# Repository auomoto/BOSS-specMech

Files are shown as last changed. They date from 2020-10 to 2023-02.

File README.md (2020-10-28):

# BOSS specMech
**_BOSS Spectrograph Mechanicals Controls for the LCO instrument_**

One of the two BOSS spectrographs will be moved to Las Campanas Observatory (LCO). Because existing spare parts inventory is not large enough to support two separate locations, we are replacing the obsolete items on the LCO instrument with currently available parts. One item is the microcontroller board, formerly a Z-World Little Giant, that is no longer manufactured (the original spectrograph was designed in the 1990s).

The new controller is built around a Microchip Curiosity Nano ATMega 4809. The source code and electronics schematics are here.

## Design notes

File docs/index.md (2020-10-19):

## References
1. [specMech Communications Guide](https://docs.google.com/document/d/16dir_fut0HBtZR5ReOcYNGfNxy1jjHzGRPkaTaeYjt8/edit?usp=sharing)
2. [BOSS Spectrograph Technical Manual](https://docs.google.com/document/d/11UHDSXXC8-JnVtt-BcFyOa2BDeodfezanSv0PJa2Pw8/edit?usp=sharing)

## Software Overview
specMech handles the motion controls and sensors on the BOSS spectrographs. The CCD readouts are handled by a different system, the Archon controller.

The specMech target processor is an Atmel ATMega4809 as implemented on a Microchip [dm320115 Curiosity Nano](https://www.microchip.com/DevelopmentTools/ProductDetails/dm320115#additional-summary) board. The programming IDE we use is Atmel Studio 7.0 although one suspects that Microchip's MPLAB X should work with few, if any, code modifications. The Curiosity Nano board was chosen because it does not need an external hardware programming tool to download sofware. Your need only the IDE software and a USB cable.

## Hardware Overview

The original SDSS spectrograph uses a Z-World Little Giant controller board. This board is no longer manufactured so we designed and built a replacment to fit. The design software used is EagleCAD with Fusion360 for layout visualization.

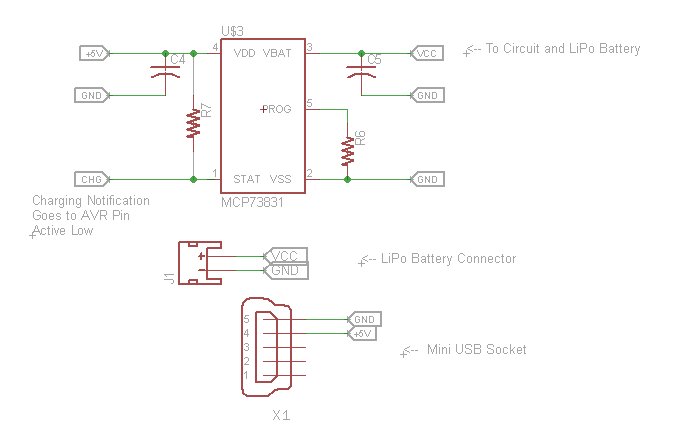
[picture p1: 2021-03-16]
Hardware/Eagle/Project/MCP73831 Circuit.PNG

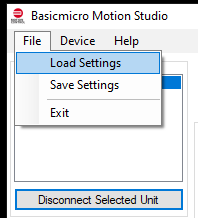
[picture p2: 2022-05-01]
Software/BasicMicro/2022-05-01 Motion Studio Load Settings.PNG

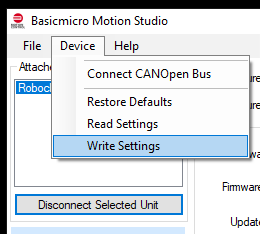
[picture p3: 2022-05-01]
Software/BasicMicro/2022-05-01 Motion Studio Write Settings.PNG

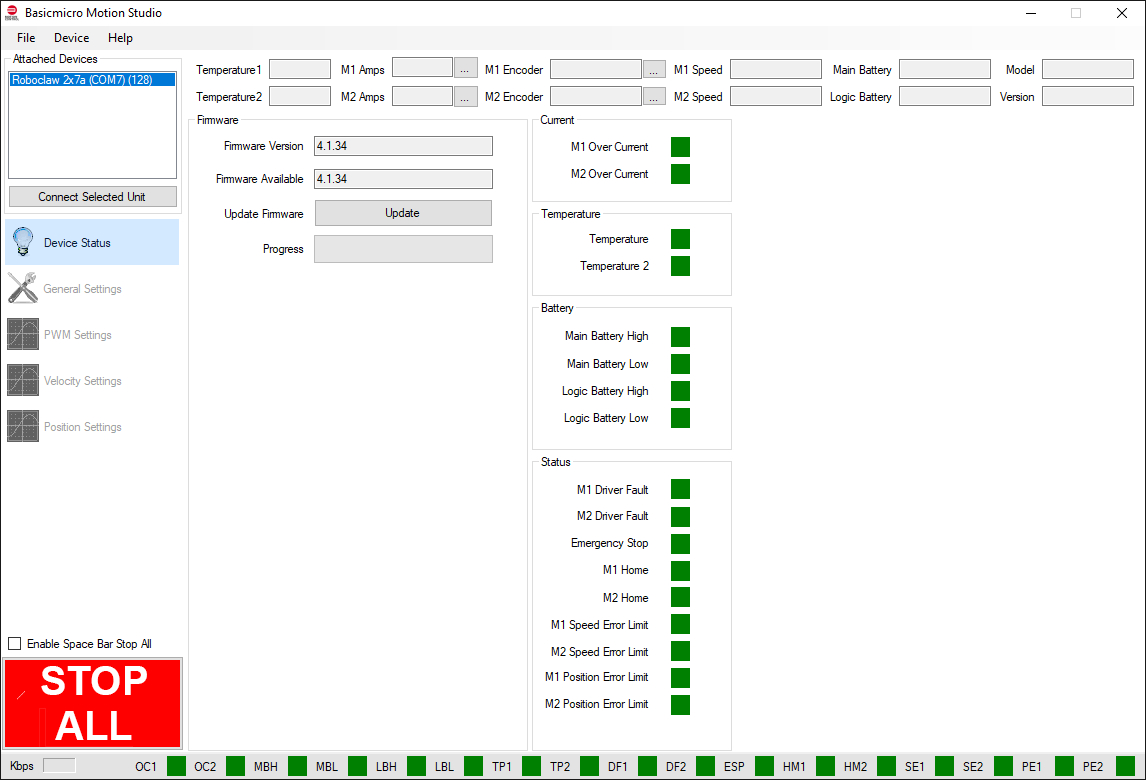
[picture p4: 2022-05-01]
Software/BasicMicro/2022-05-02 Motion Studio Screen Device Status Before.PNG

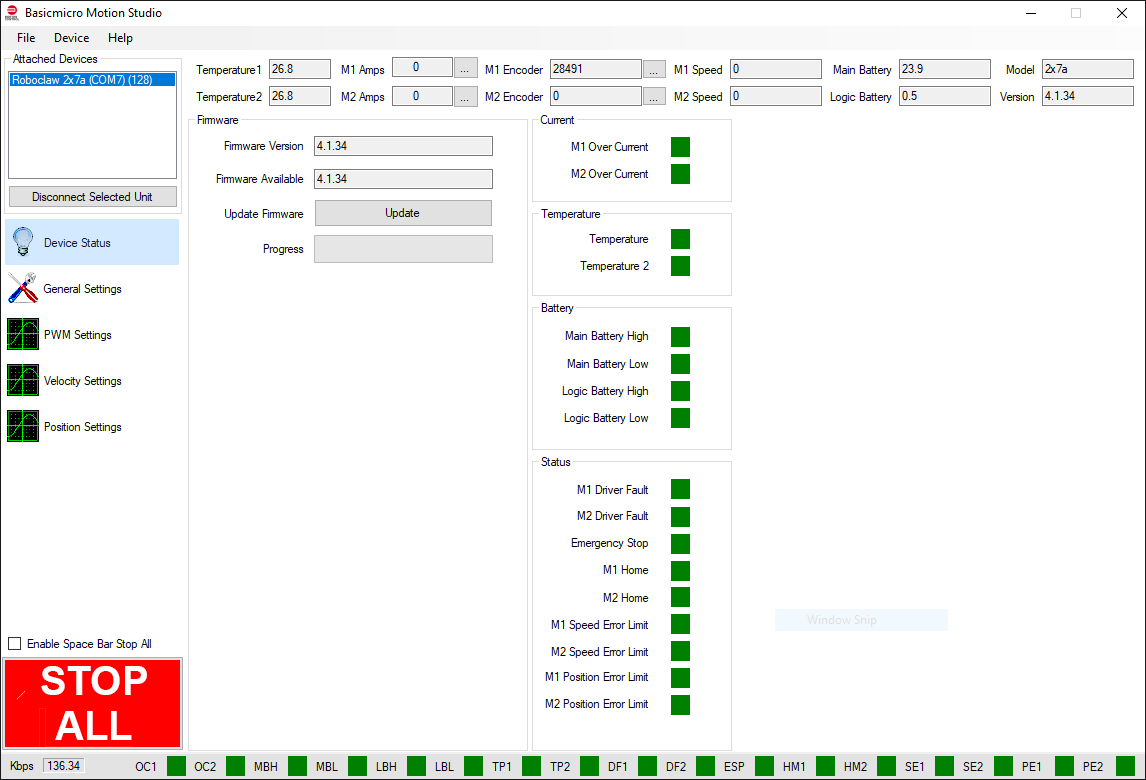
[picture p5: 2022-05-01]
Software/BasicMicro/2022-05-01 Motion Studio Screen Device Status.PNG

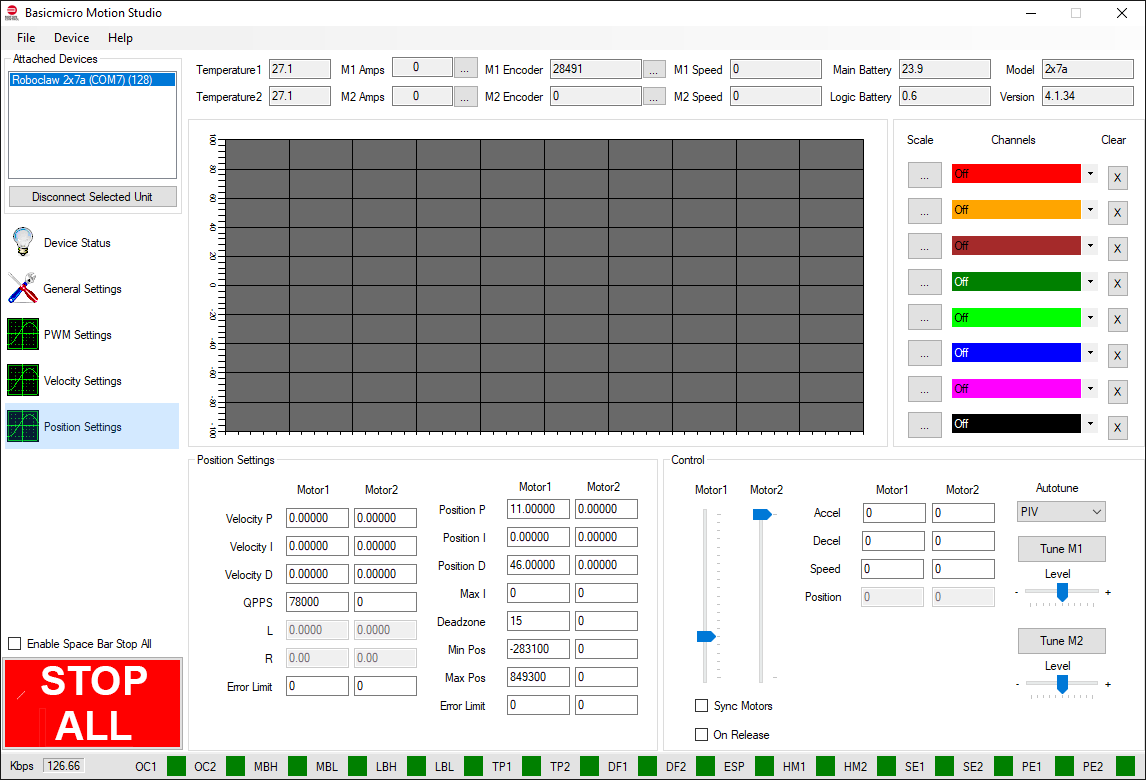
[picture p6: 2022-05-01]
Software/BasicMicro/2022-05-01 Motion Studio Screen Position Settings.PNG

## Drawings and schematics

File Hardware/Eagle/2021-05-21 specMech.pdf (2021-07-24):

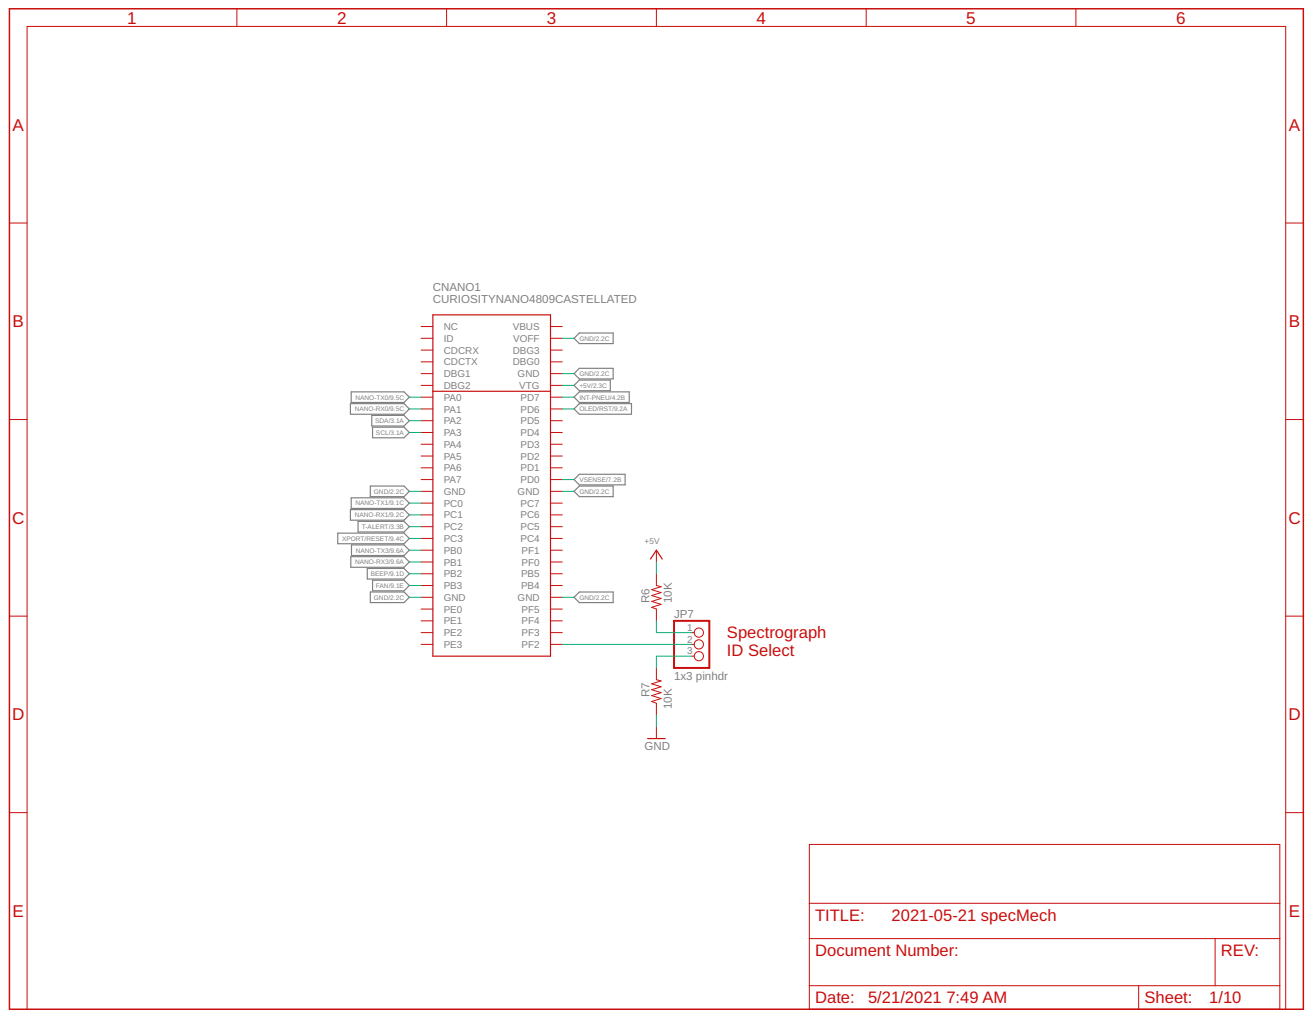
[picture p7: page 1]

Document Number: | REV:

Date: 5/21/2021 7:49 AM | Sheet: 1/10

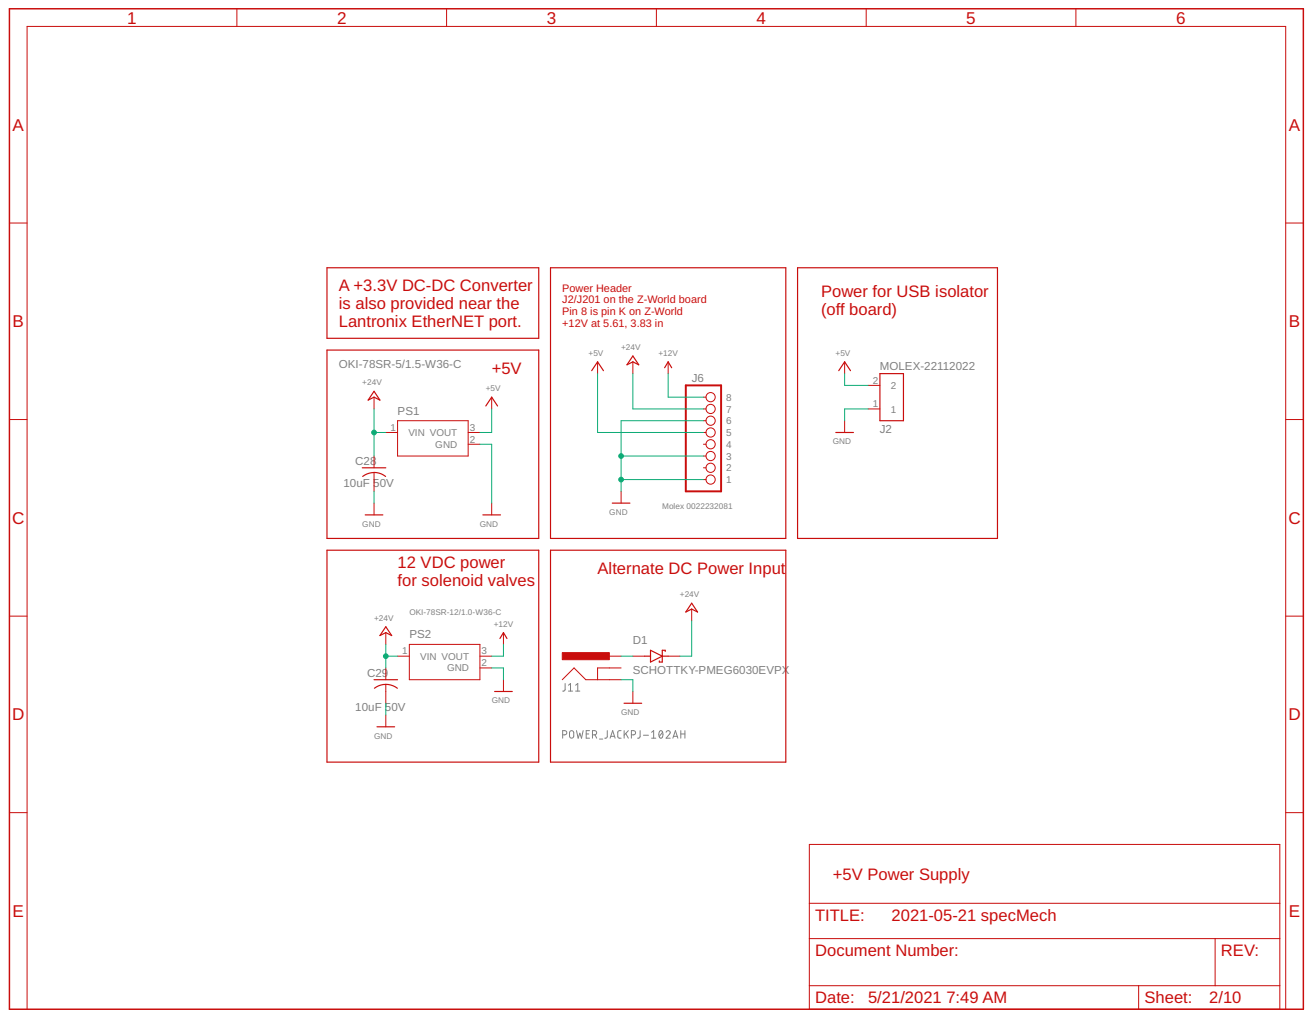
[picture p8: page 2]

Pin 8 is pin K on Z-World +12V at 5.61, 3.83 in A +3.3V DC-DC Converter
is also provided near the
Lantronix EtherNET port.

Power Header J2/J201 on the Z-World board

Power for USB isolator
(off board)

Alternate DC Power Input

Document Number: | REV:

Date: 5/21/2021 7:49 AM | Sheet: 2/10

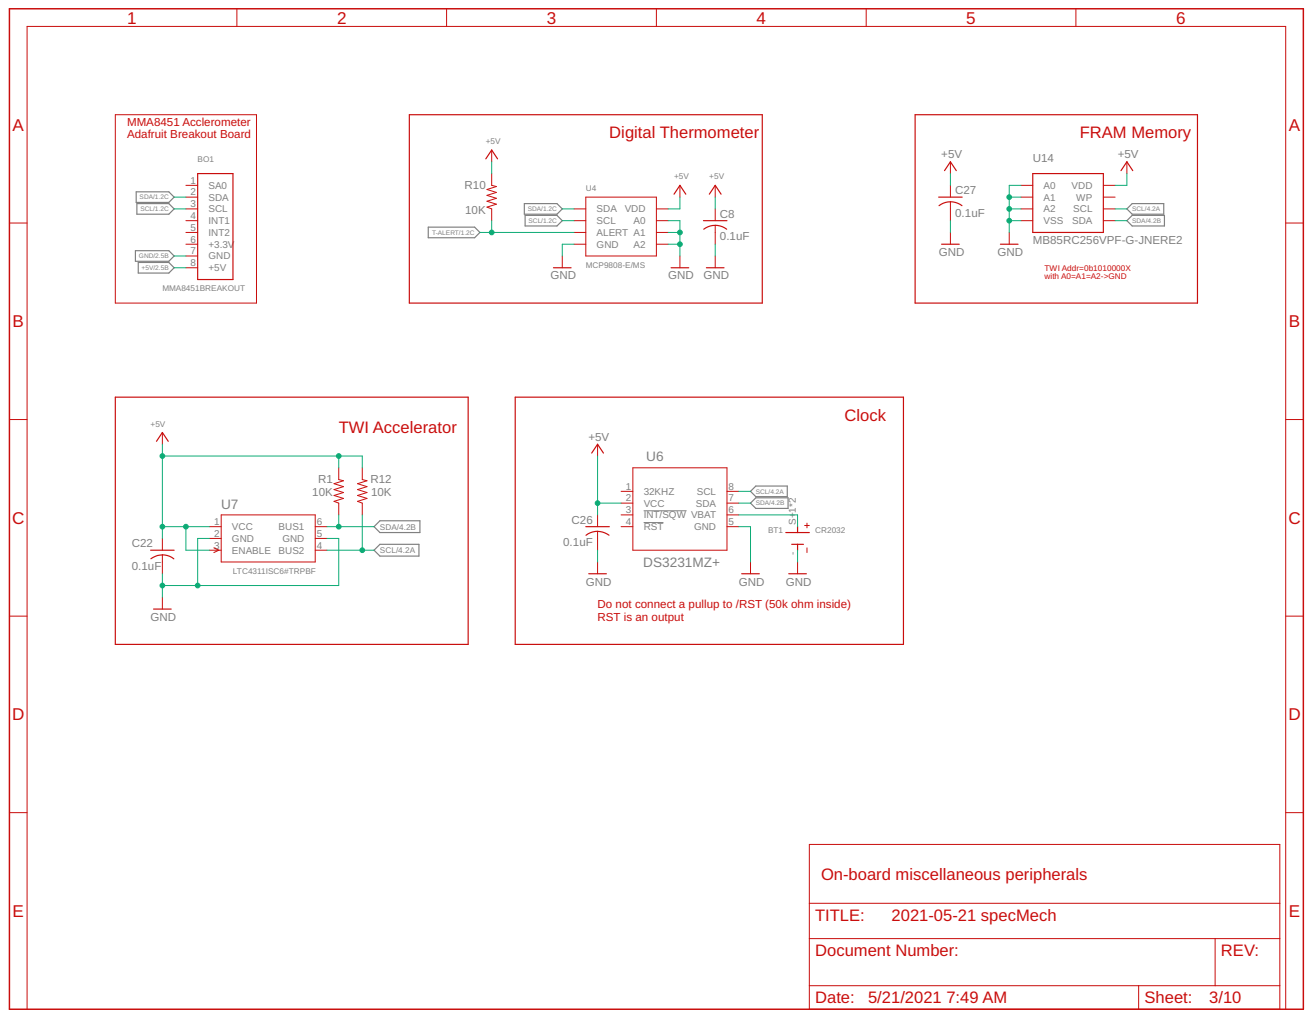
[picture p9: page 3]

MMA8451 Acclerometer Adafruit Breakout Board

TWI Addr=0b1010000X with A0=A1=A2->GND

Do not connect a pullup to /RST (50k ohm inside)
RST is an output

On-board miscellaneous peripherals

Document Number: | REV:

Date: 5/21/2021 7:49 AM | Sheet: 3/10

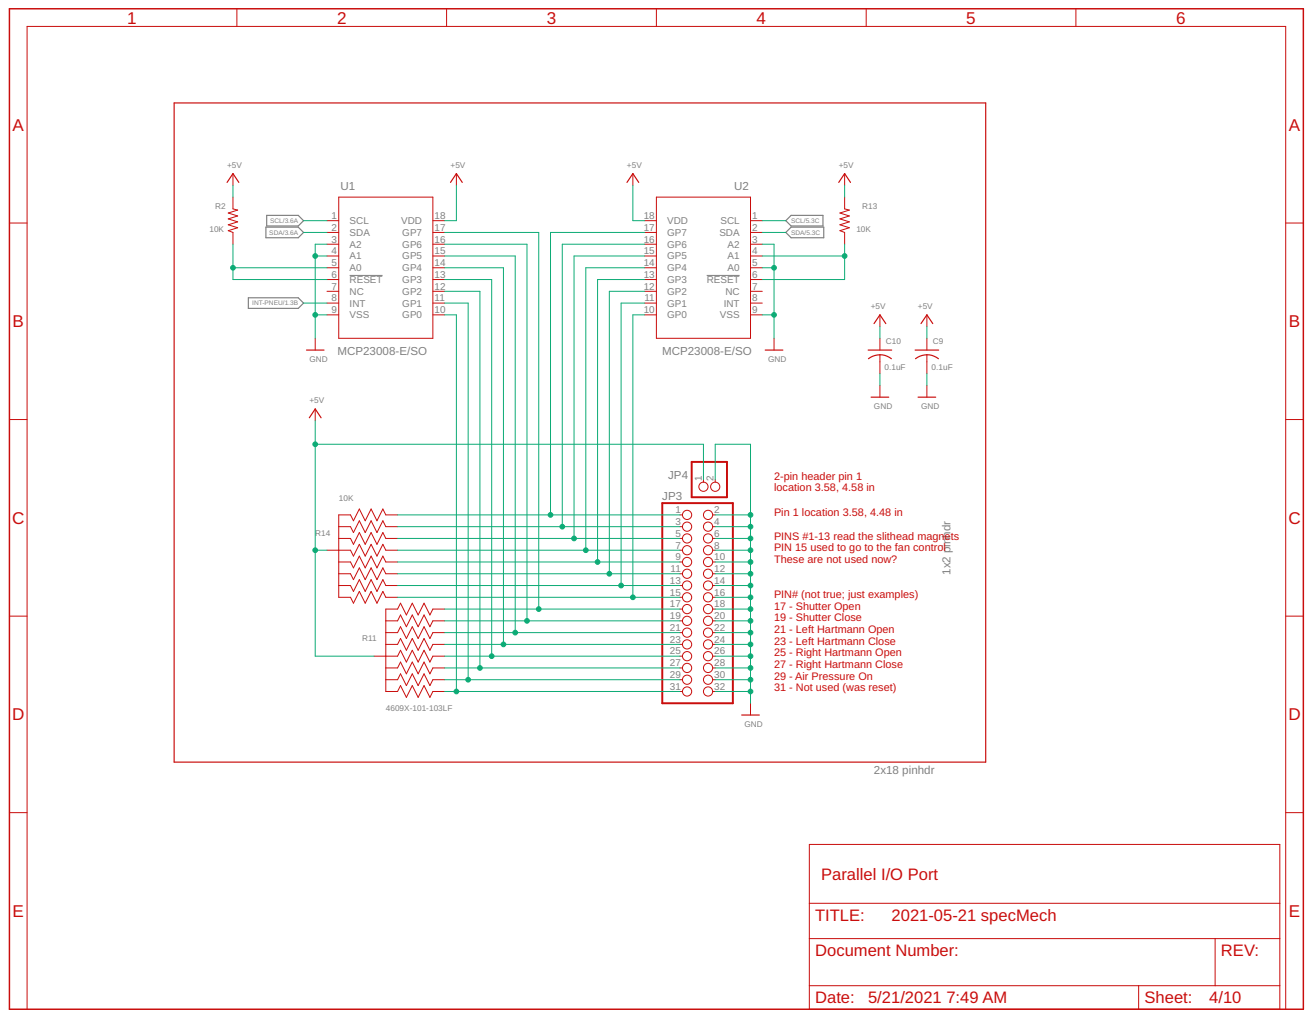
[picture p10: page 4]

Pin 1 location 3.58, 4.48 in PINS #1-13 read the slithead magnets PIN 15 used to go to the fan control

These are not used now?

PIN# (not true; just examples)
17 - Shutter Open
19 - Shutter Close
21 - Left Hartmann Open
23 - Left Hartmann Close
25 - Right Hartmann Open
27 - Right Hartmann Close
29 - Air Pressure On
31 - Not used (was reset)

Document Number: | REV:

Date: 5/21/2021 7:49 AM | Sheet: 4/10

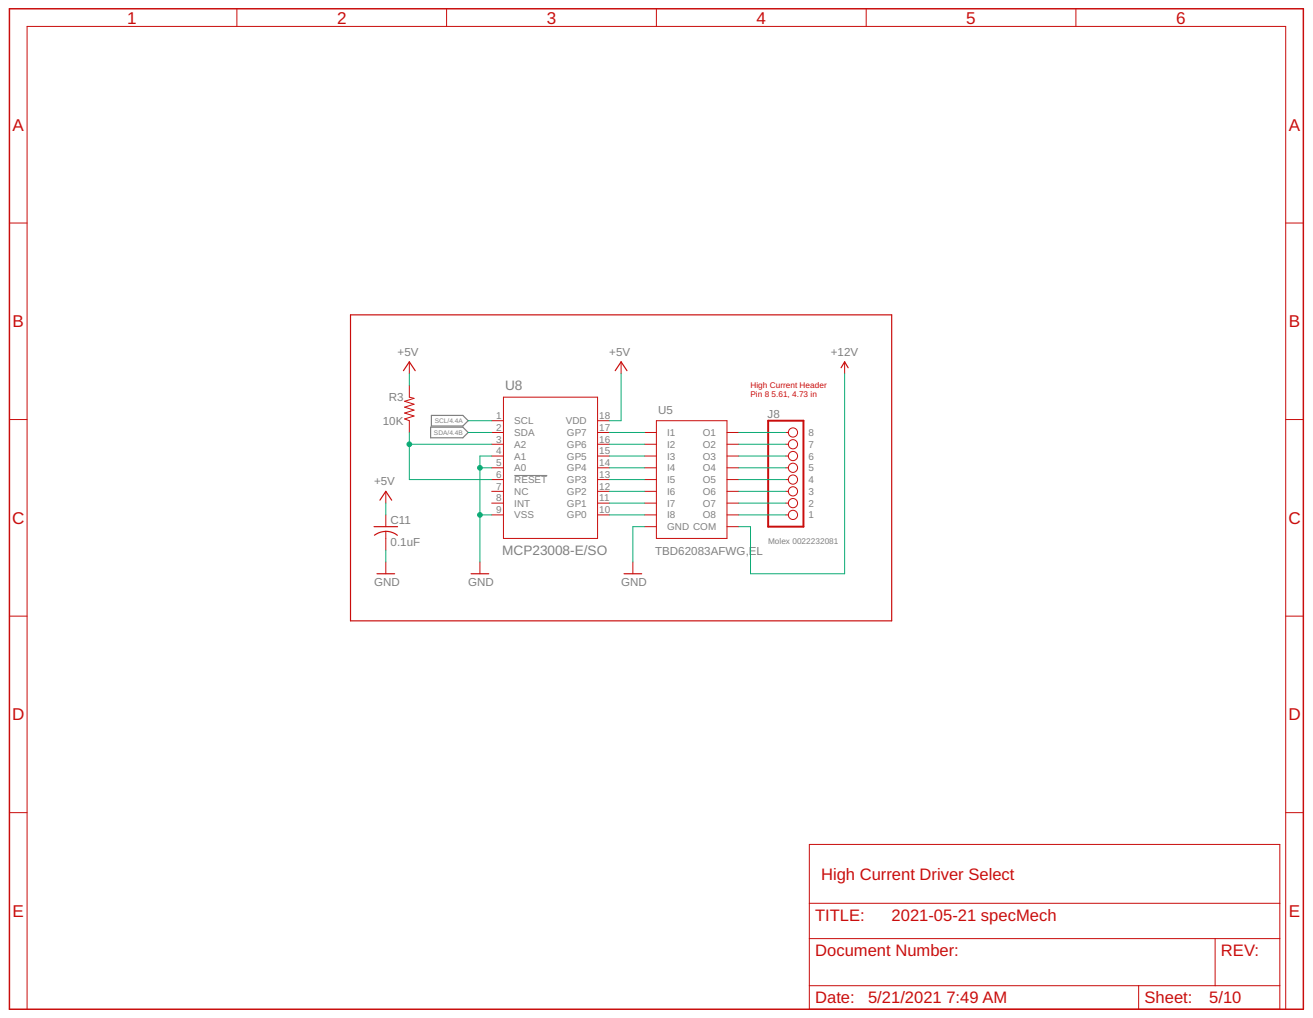
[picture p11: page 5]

High Current Header Pin 8 5.61, 4.73 in

High Current Driver Select

Document Number: | REV:

Date: 5/21/2021 7:49 AM | Sheet: 5/10

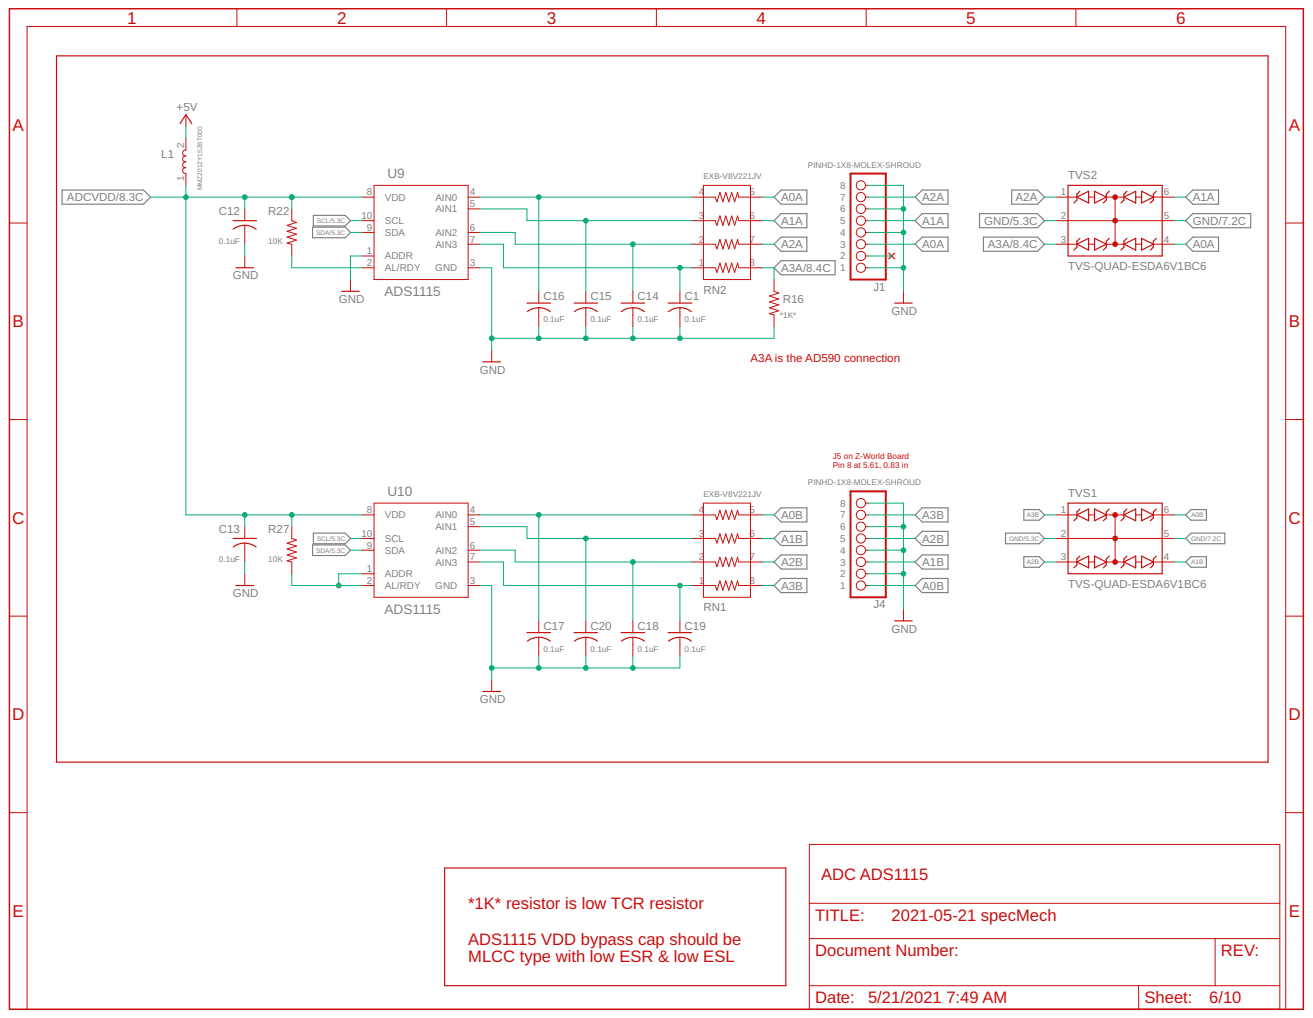
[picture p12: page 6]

J5 on Z-World Board Pin 8 at 5.61, 0.83 in

*1K* resistor is low TCR resistor

ADS1115 VDD bypass cap should be
MLCC type with low ESR & low ESL

Document Number: | REV:

Date: 5/21/2021 7:49 AM | Sheet: 6/10

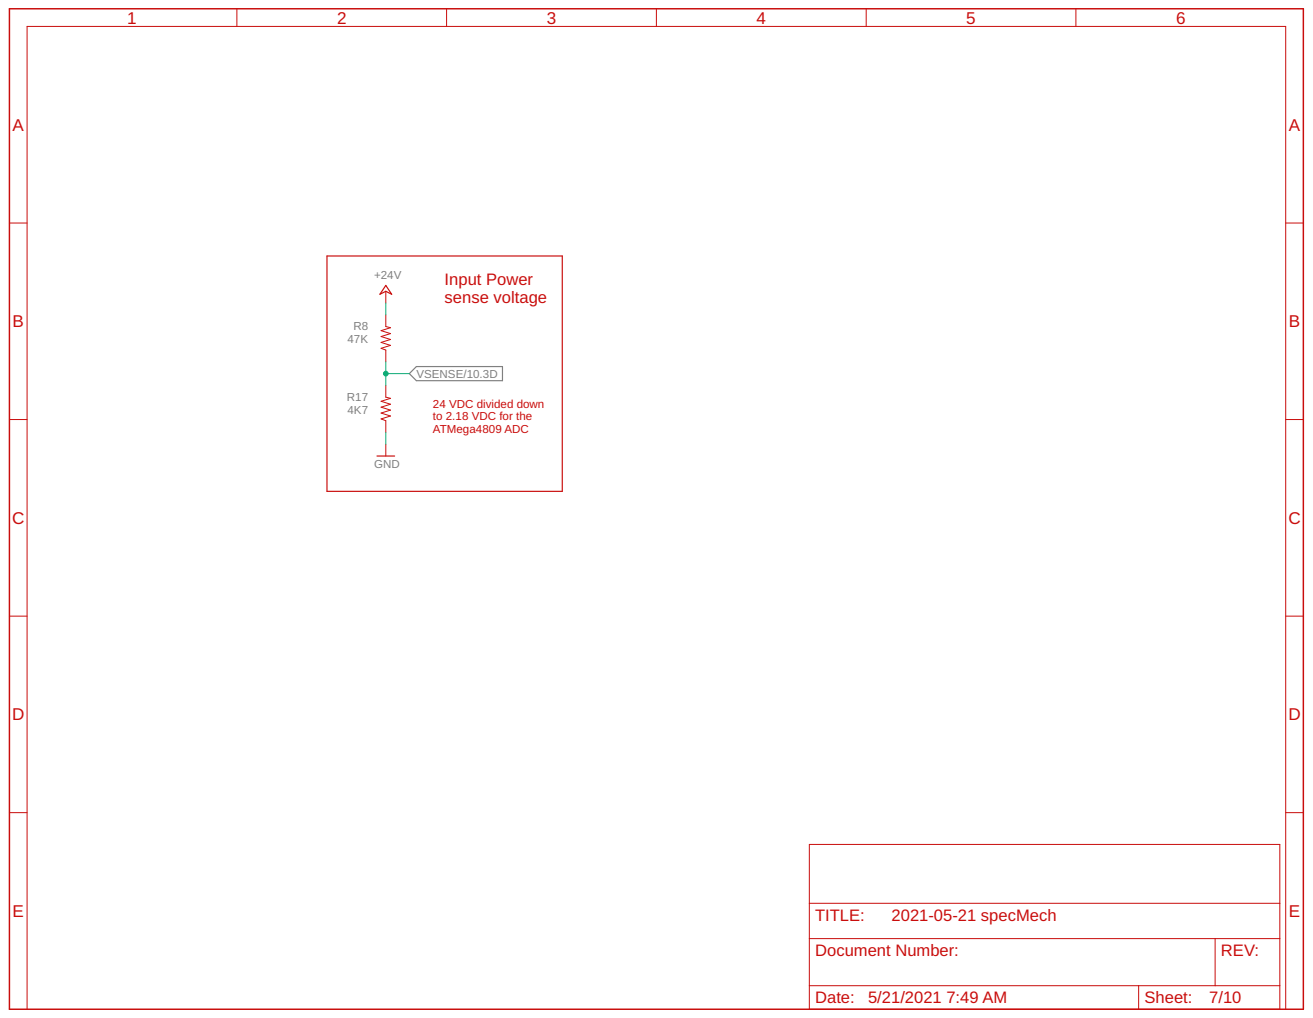
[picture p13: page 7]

24 VDC divided down
to 2.18 VDC for the ATMega4809 ADC

Document Number: | REV:

Date: 5/21/2021 7:49 AM | Sheet: 7/10

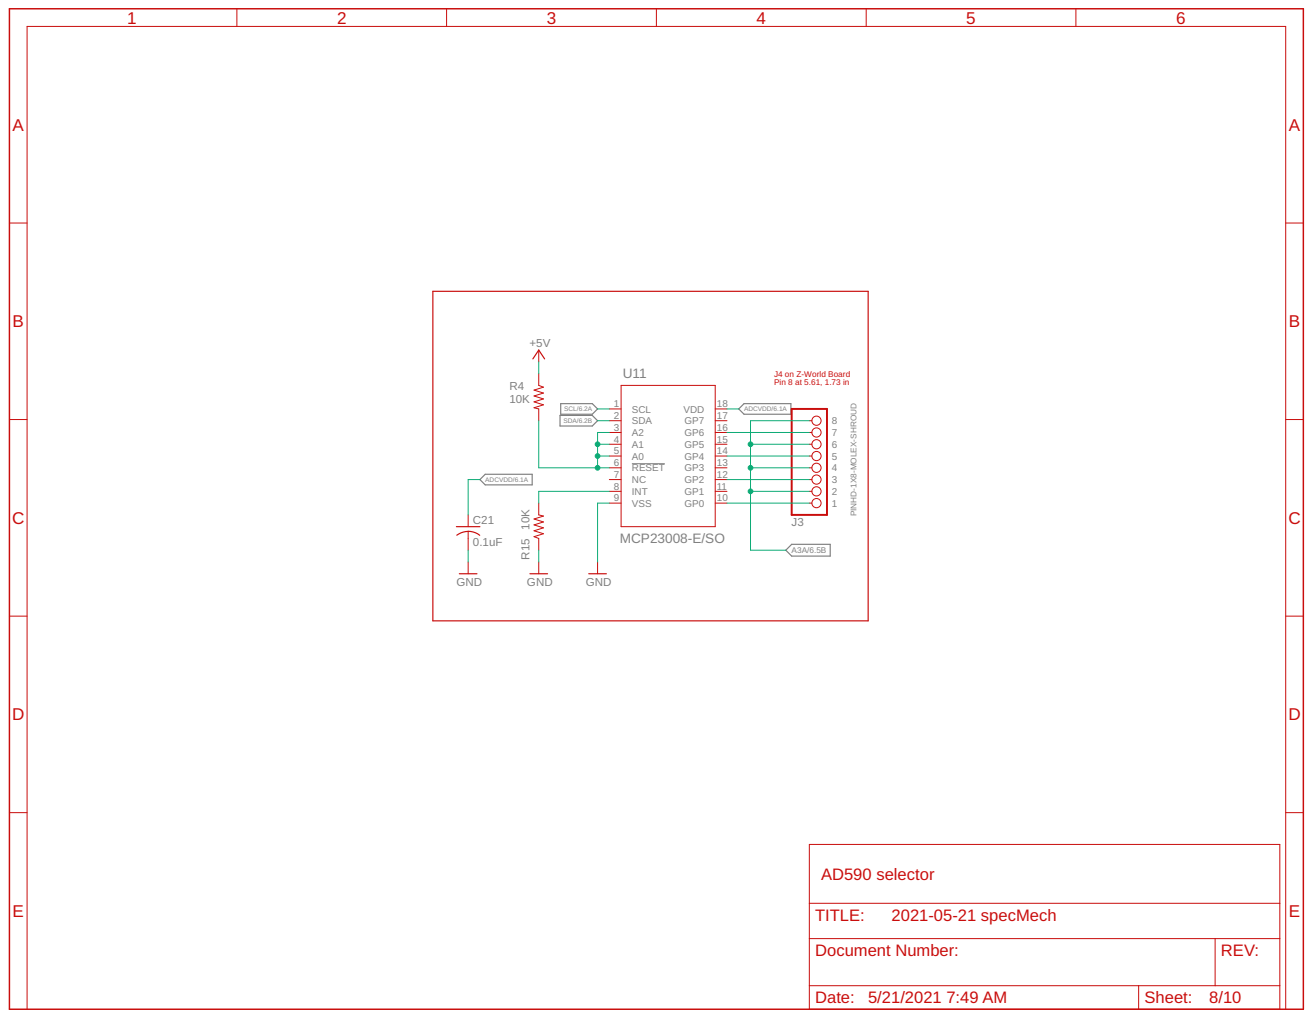
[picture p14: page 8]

J4 on Z-World Board Pin 8 at 5.61, 1.73 in

Document Number: | REV:

Date: 5/21/2021 7:49 AM | Sheet: 8/10

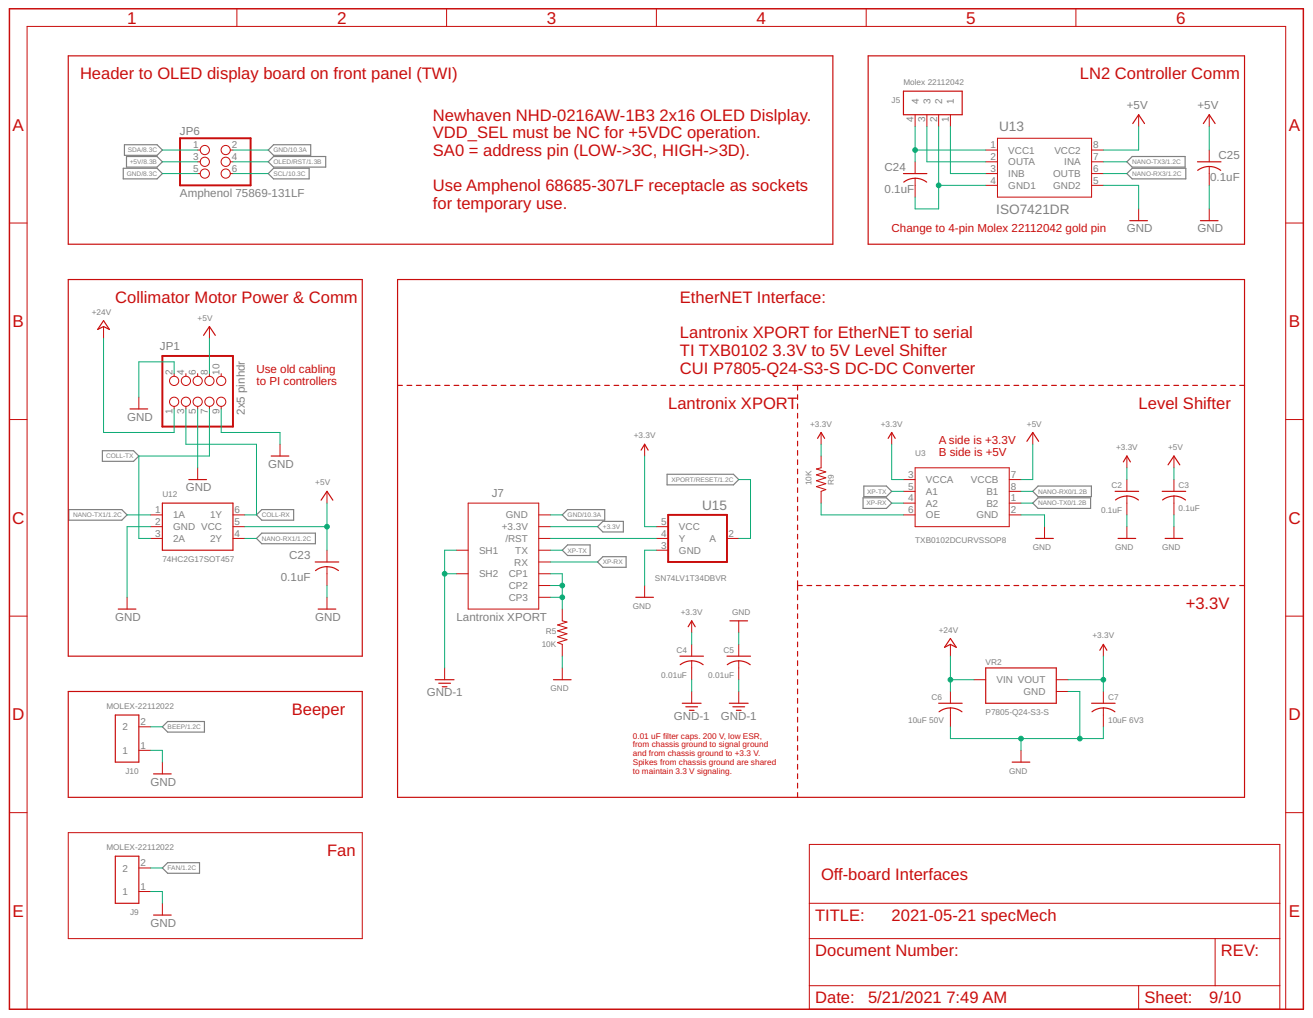
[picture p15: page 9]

Header to OLED display board on front panel (TWI)

Newhaven NHD-0216AW-1B3 2x16 OLED Dislplay. VDD_SEL must be NC for +5VDC operation. SA0 = address pin (LOW->3C, HIGH->3D). Use Amphenol 68685-307LF receptacle as sockets

Change to 4-pin Molex 22112042 gold pin

Collimator Motor Power & Comm

Lantronix XPORT for EtherNET to serial
TI TXB0102 3.3V to 5V Level Shifter
CUI P7805-Q24-S3-S DC-DC Converter

0.01 uF filter caps. 200 V, low ESR,
from chassis ground to signal ground
and from chassis ground to +3.3 V. Spikes from chassis ground are shared

Document Number: | REV:

Date: 5/21/2021 7:49 AM | Sheet: 9/10

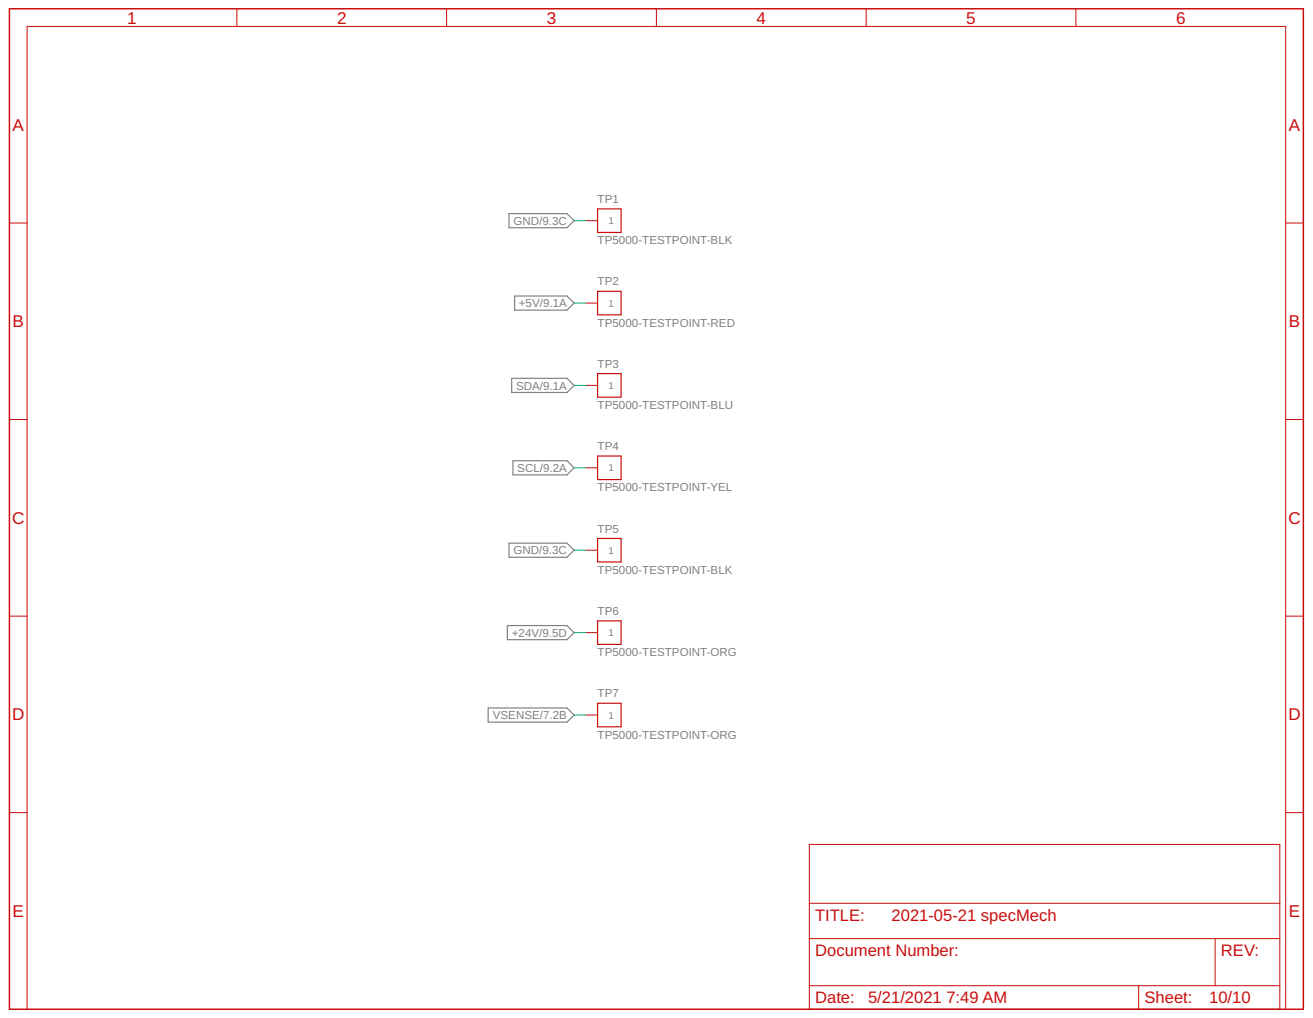
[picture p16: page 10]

Document Number: | REV:

Date: 5/21/2021 7:49 AM | Sheet: 10/10

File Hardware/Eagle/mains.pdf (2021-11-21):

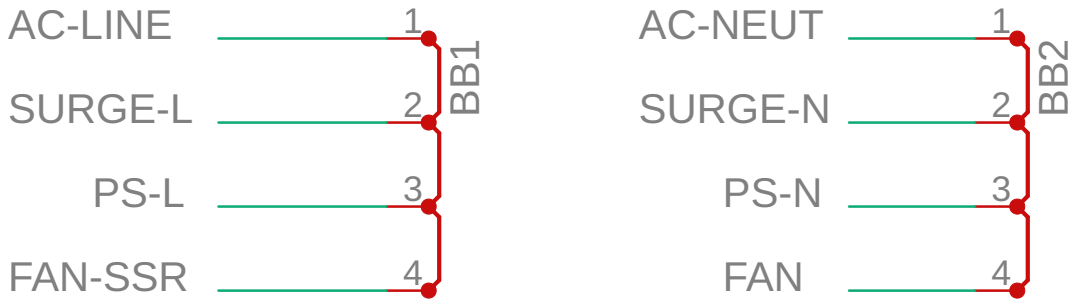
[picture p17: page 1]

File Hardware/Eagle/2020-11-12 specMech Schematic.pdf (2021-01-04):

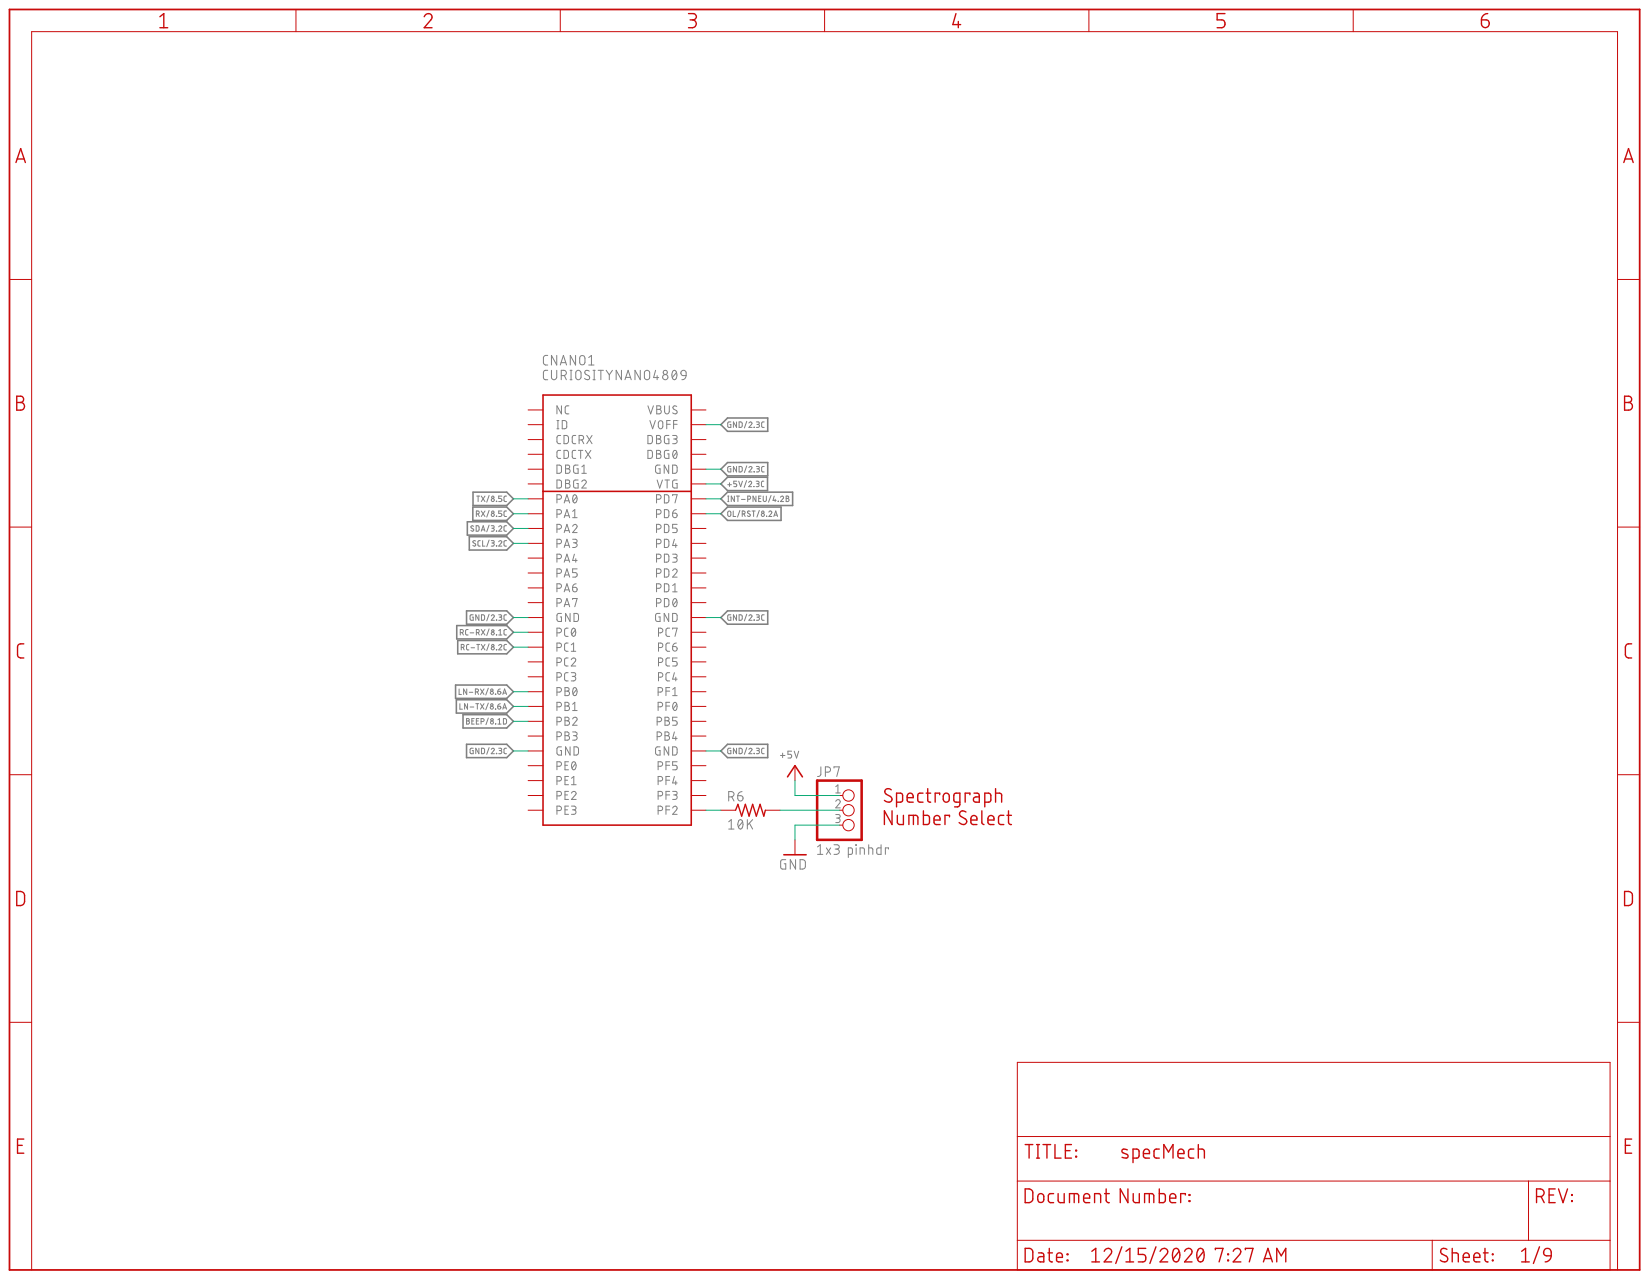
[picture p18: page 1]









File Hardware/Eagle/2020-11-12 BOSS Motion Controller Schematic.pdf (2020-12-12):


12/11/2020 4:51 PM f=1.26 G:\My Drive\Github\BOSS-specMech\Hardware\Eagle\specMech.sch (Sheet: 1/9)


12/11/2020 4:51 PM f=1.26 G:\My Drive\Github\BOSS-specMech\Hardware\Eagle\specMech.sch (Sheet: 2/9)


12/11/2020 4:51 PM f=1.26 G:\My Drive\Github\BOSS-specMech\Hardware\Eagle\specMech.sch (Sheet: 3/9)


12/11/2020 4:51 PM f=1.26 G:\My Drive\Github\BOSS-specMech\Hardware\Eagle\specMech.sch (Sheet: 4/9)


12/11/2020 4:51 PM f=1.26 G:\My Drive\Github\BOSS-specMech\Hardware\Eagle\specMech.sch (Sheet: 5/9)


12/11/2020 4:51 PM f=1.26 G:\My Drive\Github\BOSS-specMech\Hardware\Eagle\specMech.sch (Sheet: 6/9)


12/11/2020 4:51 PM f=1.26 G:\My Drive\Github\BOSS-specMech\Hardware\Eagle\specMech.sch (Sheet: 7/9)


12/11/2020 4:51 PM f=1.26 G:\My Drive\Github\BOSS-specMech\Hardware\Eagle\specMech.sch (Sheet: 8/9)


12/11/2020 4:51 PM f=1.26 G:\My Drive\Github\BOSS-specMech\Hardware\Eagle\specMech.sch (Sheet: 9/9)

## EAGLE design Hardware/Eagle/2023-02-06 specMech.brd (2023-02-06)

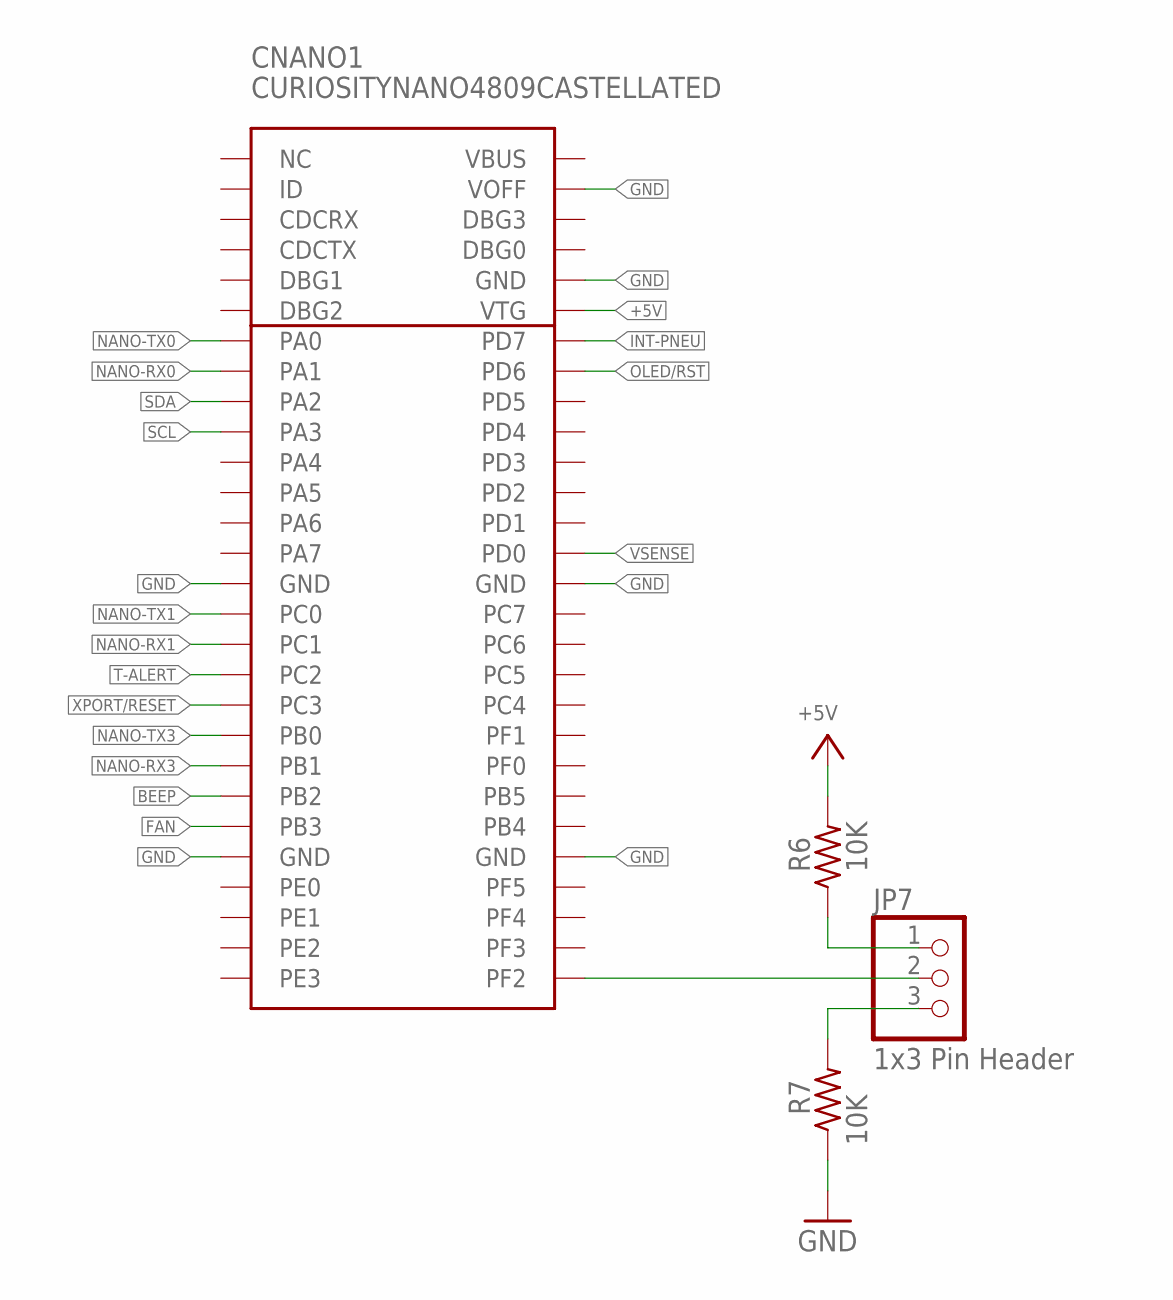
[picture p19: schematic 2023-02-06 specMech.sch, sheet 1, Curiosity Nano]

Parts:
CNANO1: CURIOSITYNANO4809CASTELLATED
JP7: 1x3 Pin Header; 1X03
R6, R7: 10K; R0805

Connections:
+5V: CNANO1.VTG, R6.2; also elsewhere on the board
BEEP: CNANO1.PB2; also elsewhere on the board
FAN: CNANO1.PB3; also elsewhere on the board
GND: CNANO1.GND15 (GND), CNANO1.GND24 (GND), CNANO1.GND33 (GND), CNANO1.GND42 (GND), CNANO1.GND52 (GND), CNANO1.VOFF, R7.1; also elsewhere on the board
INT-PNEU: CNANO1.PD7-AIN7 (PD7); also elsewhere on the board
unnamed: CNANO1.PF2, JP7.2
unnamed: JP7.3, R7.2
unnamed: JP7.1, R6.1
NANO-RX0: CNANO1.PA1-RX (PA1); also elsewhere on the board
NANO-RX1: CNANO1.PC1-RX (PC1); also elsewhere on the board
NANO-RX3: CNANO1.PB1-RX (PB1); also elsewhere on the board
NANO-TX0: CNANO1.PA0-TX (PA0); also elsewhere on the board
NANO-TX1: CNANO1.PC0-TX (PC0); also elsewhere on the board
NANO-TX3: CNANO1.PB0-TX (PB0); also elsewhere on the board
OLED/RST: CNANO1.PD6-AIN6 (PD6); also elsewhere on the board
SCL: CNANO1.PA3-SCL (PA3); also elsewhere on the board
SDA: CNANO1.PA2-SDA (PA2); also elsewhere on the board
T-ALERT: CNANO1.PC2; also elsewhere on the board
VSENSE: CNANO1.PD0-AIN0 (PD0); also elsewhere on the board
XPORT/RESET: CNANO1.PC3; also elsewhere on the board

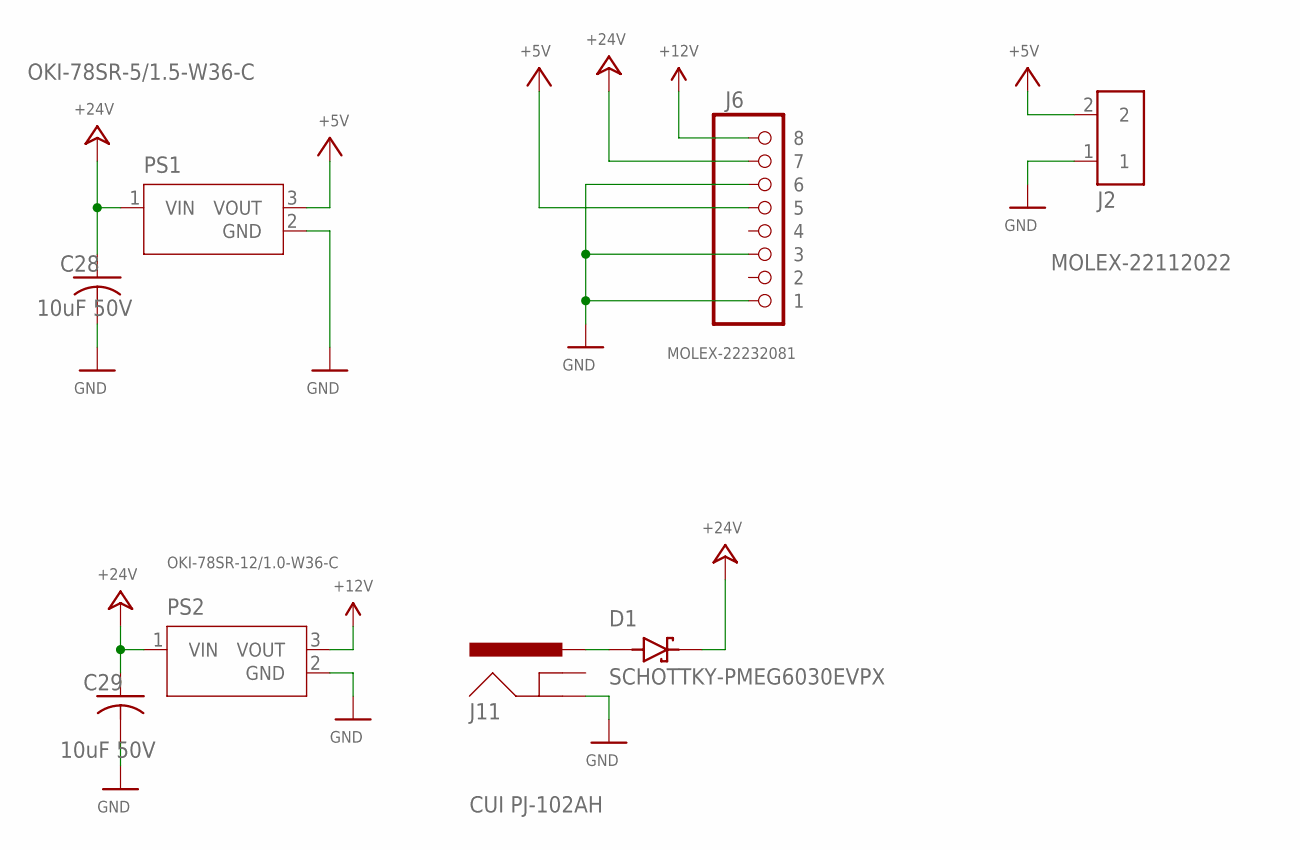
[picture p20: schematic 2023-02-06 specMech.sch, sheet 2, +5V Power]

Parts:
C28, C29: 10uF 50V; C1210
D1: SCHOTTKY-PMEG6030EVPX; DIO_PMEG6030EVPX
J2: MOLEX-22112022; 1X02-MOLEX-22112022
J6: MOLEX-22232081; 1X08-MOLEX-SHROUD
J11: CUI PJ-102AH; PJ-102AH
PS1: OKI-78SR-5/1.5-W36-C; CONV_OKI-78SR-5/1.5-W36-C
PS2: OKI-78SR-12/1.0-W36-C; CONV_OKI-78SR-5/1.5-W36-C

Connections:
+5V: J2.2, J6.P$5 (5), PS1.3 (VOUT); also elsewhere on the board
+12V: J6.P$8 (8), PS2.3 (VOUT); also elsewhere on the board
+24V: C28.1, C29.1, D1.1 (K), J6.P$7 (7), PS1.1 (VIN), PS2.1 (VIN); also elsewhere on the board
GND: C28.2, C29.2, J2.1, J6.P$1 (1), J6.P$3 (3), J6.P$6 (6), J11.GND, PS1.2 (GND), PS2.2 (GND); also elsewhere on the board
unnamed: D1.2 (A), J11.PWR

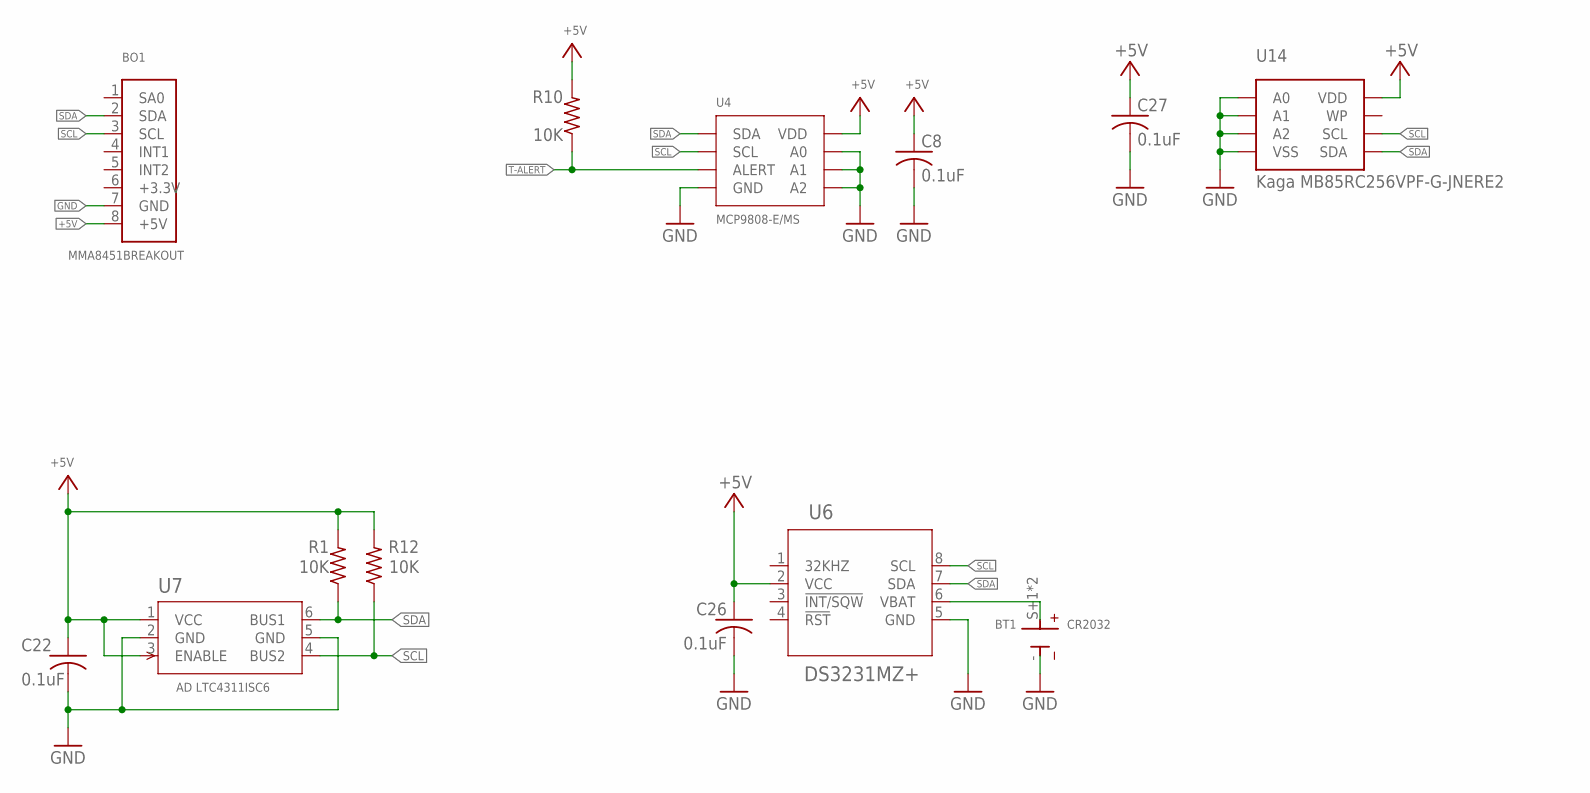
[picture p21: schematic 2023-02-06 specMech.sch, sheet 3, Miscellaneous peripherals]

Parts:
BO1: MMA8451BREAKOUT; 1X08
BT1: CR2032; BAT_BK-5058
C8, C22, C26, C27: 0.1uF; C0805
R1, R10, R12: 10K; R0805
U4: MCP9808-E/MS; MSOP8_MC_MCH
U6: DS3231MZ+; 21-0041B_8
U7: AD LTC4311ISC6; SOT-6_SC_LIT
U14: Kaga MB85RC256VPF-G-JNERE2; SOIC127P797X210-8N

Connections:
+5V: BO1.8 (+5V), C8.1, C22.1, C26.1, C27.1, R1.2, R10.2, R12.2, U4.8 (VDD), U6.2 (VCC), U7.1 (VCC), U7.3 (ENABLE), U14.8 (VDD); also elsewhere on the board
GND: BO1.7 (GND), BT1.-, C8.2, C22.2, C26.2, C27.2, U4.4 (GND), U4.5 (A2), U4.6 (A1), U4.7 (A0), U6.5 (GND), U7.2 (GND), U7.5 (GND), U14.1 (A0), U14.2 (A1), U14.3 (A2), U14.4 (VSS); also elsewhere on the board
SCL: BO1.3 (SCL), R12.1, U4.2 (SCL), U6.8 (SCL), U7.4 (BUS2), U14.6 (SCL); also elsewhere on the board
SDA: BO1.2 (SDA), R1.1, U4.1 (SDA), U6.7 (SDA), U7.6 (BUS1), U14.5 (SDA); also elsewhere on the board
T-ALERT: R10.1, U4.3 (ALERT); also elsewhere on the board
VBAT: BT1.S+1 (+), BT1.S+2 (+), U6.6 (VBAT)

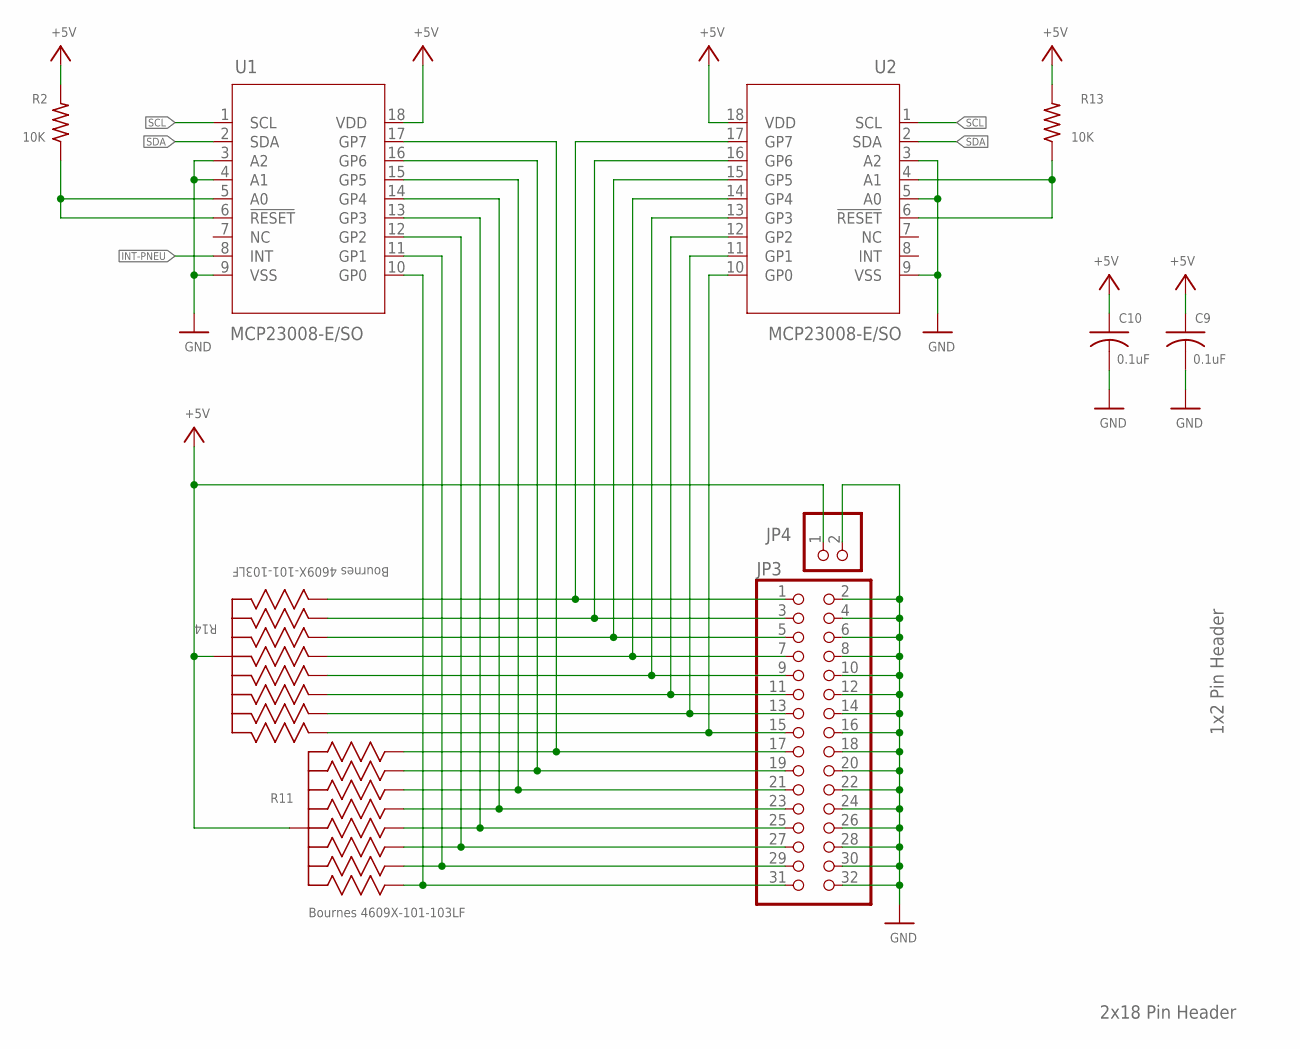
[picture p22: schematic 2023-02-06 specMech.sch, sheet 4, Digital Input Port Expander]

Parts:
C9, C10: 0.1uF; C0805
JP3: 2x18 Pin Header; 2X16
JP4: 1x2 Pin Header; 1X02
R2, R13: 10K; R0805
R11, R14: Bournes 4609X-101-103LF; BO_4609X
U1, U2: MCP23008-E/SO; SOIC18-W_MC

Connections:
+5V: C9.1, C10.1, JP4.1, R2.2, R11.1, R13.2, R14.1, U1.18 (VDD), U2.18 (VDD); also elsewhere on the board
GND: C9.2, C10.2, JP3.2, JP3.4, JP3.6, JP3.8, JP3.10, JP3.12, JP3.14, JP3.16, JP3.18, JP3.20, JP3.22, JP3.24, JP3.26, JP3.28, JP3.30, JP3.32, JP4.2, U1.3 (A2), U1.4 (A1), U1.9 (VSS), U2.3 (A2), U2.5 (A0), U2.9 (VSS); also elsewhere on the board
INT-PNEU: U1.8 (INT); also elsewhere on the board
unnamed: JP3.1, R14.2, U2.17 (GP7)
unnamed: JP3.3, R14.3, U2.16 (GP6)
unnamed: JP3.5, R14.4, U2.15 (GP5)
unnamed: JP3.7, R14.5, U2.14 (GP4)
unnamed: JP3.17, R11.9, U1.17 (GP7)
unnamed: JP3.19, R11.8, U1.16 (GP6)
unnamed: JP3.21, R11.7, U1.15 (GP5)
unnamed: JP3.23, R11.6, U1.14 (GP4)
unnamed: JP3.25, R11.5, U1.13 (GP3)
unnamed: R2.1, U1.5 (A0), U1.6 (!RESET)
unnamed: JP3.29, R11.3, U1.11 (GP1)
unnamed: JP3.31, R11.2, U1.10 (GP0)
unnamed: JP3.11, R14.7, U2.12 (GP2)
unnamed: JP3.27, R11.4, U1.12 (GP2)
unnamed: JP3.13, R14.8, U2.11 (GP1)
unnamed: JP3.15, R14.9, U2.10 (GP0)
unnamed: R13.1, U2.4 (A1), U2.6 (!RESET)
unnamed: JP3.9, R14.6, U2.13 (GP3)
SCL: U1.1 (SCL), U2.1 (SCL); also elsewhere on the board
SDA: U1.2 (SDA), U2.2 (SDA); also elsewhere on the board

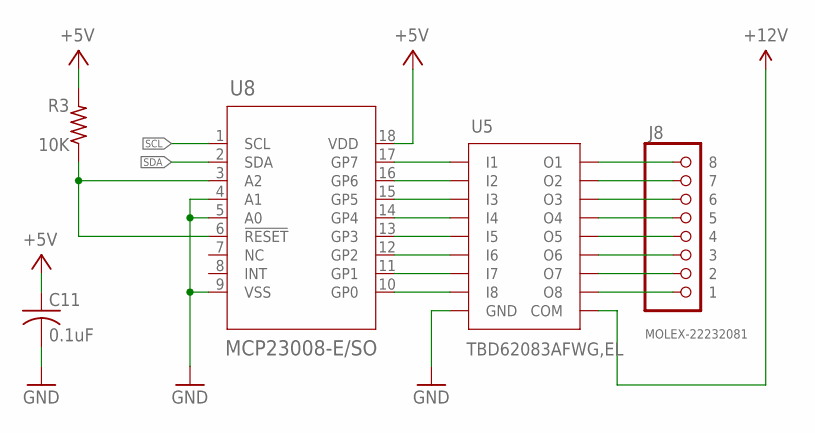
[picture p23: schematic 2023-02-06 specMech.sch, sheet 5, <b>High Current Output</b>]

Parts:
C11: 0.1uF; C0805
J8: MOLEX-22232081; 1X08-MOLEX-SHROUD
R3: 10K; R0805
U5: TBD62083AFWG,EL; SOIC127P1030X245-18
U8: MCP23008-E/SO; SOIC18-W_MC

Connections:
+5V: C11.1, R3.2, U8.18 (VDD); also elsewhere on the board
+12V: U5.10 (COM); also elsewhere on the board
GND: C11.2, U5.9 (GND), U8.4 (A1), U8.5 (A0), U8.9 (VSS); also elsewhere on the board
unnamed: U5.1 (I1), U8.17 (GP7)
unnamed: U5.2 (I2), U8.16 (GP6)
unnamed: U5.3 (I3), U8.15 (GP5)
unnamed: U5.4 (I4), U8.14 (GP4)
unnamed: U5.5 (I5), U8.13 (GP3)
unnamed: U5.6 (I6), U8.12 (GP2)
unnamed: U5.7 (I7), U8.11 (GP1)
unnamed: U5.8 (I8), U8.10 (GP0)
unnamed: R3.1, U8.3 (A2), U8.6 (!RESET)
unnamed: J8.P$8 (8), U5.18 (O1)
unnamed: J8.P$1 (1), U5.11 (O8)
unnamed: J8.P$2 (2), U5.12 (O7)
unnamed: J8.P$3 (3), U5.13 (O6)
unnamed: J8.P$4 (4), U5.14 (O5)
unnamed: J8.P$5 (5), U5.15 (O4)
unnamed: J8.P$6 (6), U5.16 (O3)
unnamed: J8.P$7 (7), U5.17 (O2)
SCL: U8.1 (SCL); also elsewhere on the board
SDA: U8.2 (SDA); also elsewhere on the board

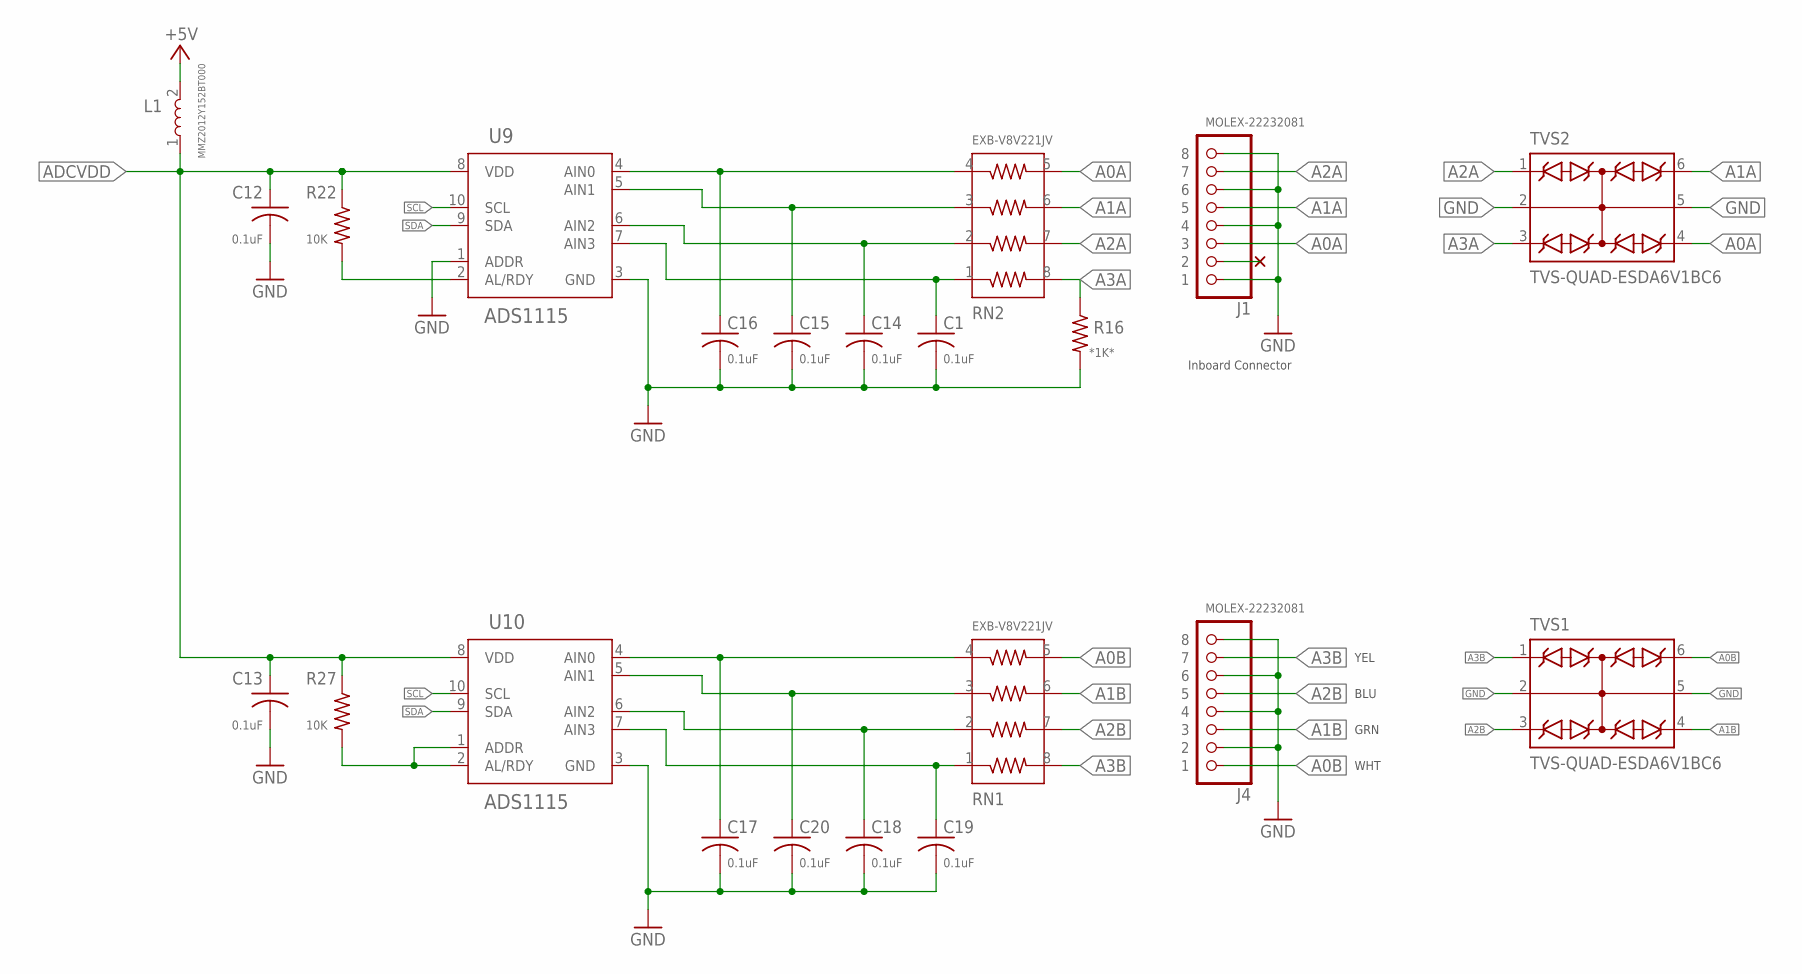
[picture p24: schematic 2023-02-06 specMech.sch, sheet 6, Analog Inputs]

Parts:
C1, C12, C13, C14, C15, C16, C17, C18, C19, C20: 0.1uF; C0805
J1, J4: MOLEX-22232081; 1X08-MOLEX-SHROUD
L1: MMZ2012Y152BT000; INDC2012X87N
R16: *1K*; R0805
R22, R27: 10K; R0805
RN1, RN2: EXB-V8V221JV; EXB38V_PAN
TVS1, TVS2: TVS-QUAD-ESDA6V1BC6; SOT95P280X145-6N
U9, U10: ADS1115; SOP50P490X110-10N

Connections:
+5V: L1.2; also elsewhere on the board
A0A: J1.P$3 (3), RN2.5, TVS2.4 (C3)
A0B: J4.P$1 (1), RN1.5, TVS1.6 (C4)
A1A: J1.P$5 (5), RN2.6, TVS2.6 (C4)
A1B: J4.P$3 (3), RN1.6, TVS1.4 (C3)
A2A: J1.P$7 (7), RN2.7, TVS2.1 (C1)
A2B: J4.P$5 (5), RN1.7, TVS1.3 (C2)
A3A: R16.1, RN2.8, TVS2.3 (C2); also elsewhere on the board
A3B: J4.P$7 (7), RN1.8, TVS1.1 (C1)
ADCVDD: C12.1, C13.1, L1.1, R22.1, R27.1, U9.8 (VDD), U10.8 (VDD); also elsewhere on the board
GND: C1.2, C12.2, C13.2, C14.2, C15.2, C16.2, C17.2, C18.2, C19.2, C20.2, J1.P$1 (1), J1.P$4 (4), J1.P$6 (6), J1.P$8 (8), J4.P$2 (2), J4.P$4 (4), J4.P$6 (6), J4.P$8 (8), R16.2, TVS1.2 (CC1), TVS1.5 (CC2), TVS2.2 (CC1), TVS2.5 (CC2), U9.1 (ADDR), U9.3 (GND), U10.3 (GND); also elsewhere on the board
unnamed: C1.1, RN2.1, U9.7 (AIN3)
unnamed: C16.1, RN2.4, U9.4 (AIN0)
unnamed: C15.1, RN2.3, U9.5 (AIN1)
unnamed: R22.2, U9.2 (AL/RDY)
unnamed: C19.1, RN1.1, U10.7 (AIN3)
unnamed: C14.1, RN2.2, U9.6 (AIN2)
unnamed: C18.1, RN1.2, U10.6 (AIN2)
unnamed: C20.1, RN1.3, U10.5 (AIN1)
unnamed: C17.1, RN1.4, U10.4 (AIN0)
unnamed: R27.2, U10.1 (ADDR), U10.2 (AL/RDY)
SCL: U9.10 (SCL), U10.10 (SCL); also elsewhere on the board
SDA: U9.9 (SDA), U10.9 (SDA); also elsewhere on the board

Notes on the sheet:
WHT
GRN
YEL
BLU
Inboard Connector

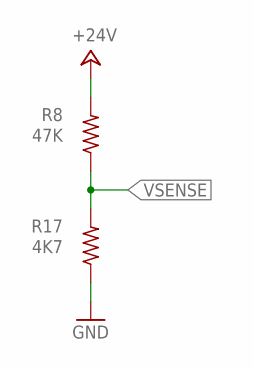
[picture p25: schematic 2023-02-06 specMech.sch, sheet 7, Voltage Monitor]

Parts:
R8: 47K; R0805
R17: 4K7; R0805

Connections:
+24V: R8.2; also elsewhere on the board
GND: R17.1; also elsewhere on the board
VSENSE: R8.1, R17.2; also elsewhere on the board

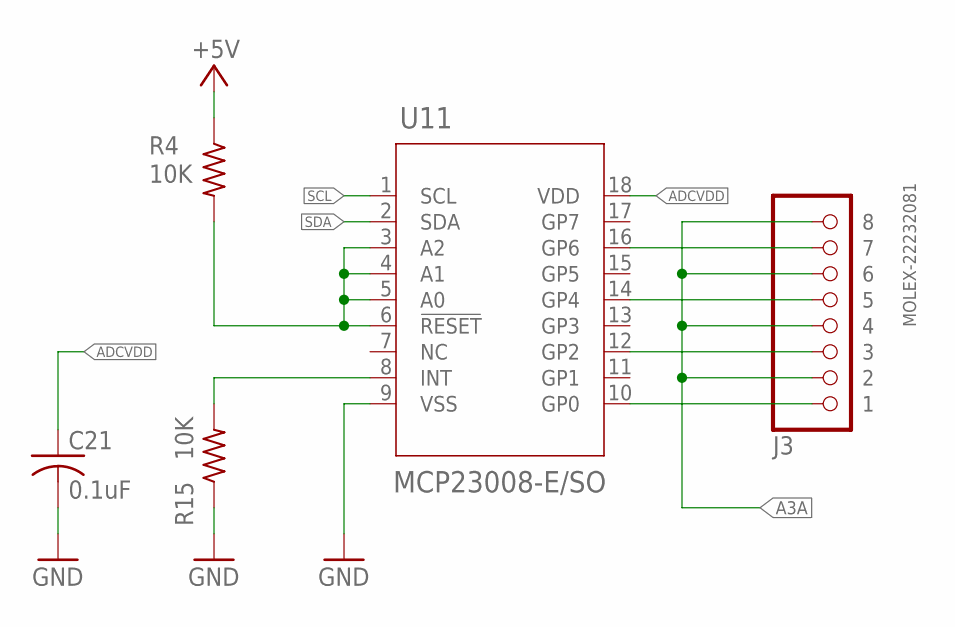
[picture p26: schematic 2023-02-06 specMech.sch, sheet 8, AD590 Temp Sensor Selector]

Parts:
C21: 0.1uF; C0805
J3: MOLEX-22232081; 1X08-MOLEX-SHROUD
R4, R15: 10K; R0805
U11: MCP23008-E/SO; SOIC18-W_MC

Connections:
+5V: R4.1; also elsewhere on the board
A3A: J3.P$2 (2), J3.P$4 (4), J3.P$6 (6), J3.P$8 (8); also elsewhere on the board
ADCVDD: C21.1, U11.18 (VDD); also elsewhere on the board
GND: C21.2, R15.1, U11.9 (VSS); also elsewhere on the board
unnamed: R4.2, U11.3 (A2), U11.4 (A1), U11.5 (A0), U11.6 (!RESET)
unnamed: R15.2, U11.8 (INT)
unnamed: J3.P$1 (1), U11.10 (GP0)
unnamed: J3.P$3 (3), U11.12 (GP2)
unnamed: J3.P$5 (5), U11.14 (GP4)
unnamed: J3.P$7 (7), U11.16 (GP6)
SCL: U11.1 (SCL); also elsewhere on the board
SDA: U11.2 (SDA); also elsewhere on the board

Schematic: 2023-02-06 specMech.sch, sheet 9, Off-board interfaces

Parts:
C2, C3, C23, C24, C25: 0.1uF; C0805
C4, C5: 0.01uF; C0805
C6: 10uF 50V; C1210
C7: 10uF 6V3; C0805
J7: Lantronix XPORT; XPORT-2
J9, J10: MOLEX-22112022; 1X02-MOLEX-22112022
J12: MOLEX-22112062; 1X06-MOLEX-22112062
JP1: 2x5 Pin Header; 2X05
JP2, JP5: 1x2 Pin Header; 1X02
JP6: Amphenol 75869-131LF; PINHD-2X3-SHROUDED
R5, R9: 10K; R0805
U3: TXB0102DCURVSSOP8; GHI-IC_VSSOP8(TI)
U12: 74HC2G17SOT457; SOP95P275X110-6
U13: ISO7421DR; SOIC127P599X175-8N
U15: SN74LV1T34DBVR; SOT95P280X145-5N
VR2: P7805-Q24-S3-S; CONV_P7805-Q24-S3-S

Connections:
+3.3V: C2.1, C4.1, C7.1, J7.3.3V (+3.3V), R9.2, U3.3 (VCCA), U15.5 (VCC), VR2.VOUT
+5V: C3.1, C23.1, C25.1, J12.6, JP1.8, JP2.2, JP6.3, U3.7 (VCCB), U12.5 (VCC), U13.8 (VCC2); also elsewhere on the board
+24V: C6.1, JP1.1, VR2.VIN; also elsewhere on the board
BEEP: J10.2; also elsewhere on the board
COLL-RX: JP1.3, U12.6 (1Y)
COLL-TX: JP1.7, U12.3 (2A)
CP3: J7.CP1, J7.CP2, J7.CP3, R5.2
FAN: J9.2; also elsewhere on the board
GND: C2.2, C3.2, C5.1, C6.2, C7.2, C23.2, C25.2, J7.GND, J9.1, J10.1, J12.5, JP1.2, JP1.5, JP1.9, JP5.2, JP6.2, JP6.5, R5.1, U3.2 (GND), U12.2 (GND), U13.5 (GND2), U15.3 (GND), VR2.GND; also elsewhere on the board
GND1: C24.2, J12.2, JP5.1, U13.4 (GND1)
GND-1: C4.2, C5.2, J7.P$1 (SH1), J7.P$2 (SH2)
INB: J12.1, U13.3 (INB)
unnamed: R9.1, U3.6 (OE)
NANO-RX0: U3.8 (B1); also elsewhere on the board
NANO-RX1: U12.4 (2Y); also elsewhere on the board
NANO-RX3: U13.6 (OUTB); also elsewhere on the board
NANO-TX0: U3.1 (B2); also elsewhere on the board
NANO-TX1: U12.1 (1A); also elsewhere on the board
NANO-TX3: U13.7 (INA); also elsewhere on the board
OLED/RST: JP6.4; also elsewhere on the board
OUTA: J12.3, U13.2 (OUTA)
SCL: JP6.6; also elsewhere on the board
SDA: JP6.1; also elsewhere on the board
VCC1: C24.1, J12.4, JP2.1, U13.1 (VCC1)
XP-RX: J7.RX, U3.4 (A2)
XP-TX: J7.TX, U3.5 (A1)
XP/RST: J7./RST, U15.4 (Y)
XPORT/RESET: U15.2 (A); also elsewhere on the board

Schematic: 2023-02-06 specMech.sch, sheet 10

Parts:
TP1, TP5: TP5000-TESTPOINT-BLK
TP2: TP5000-TESTPOINT-RED
TP3: TP5000-TESTPOINT-BLU
TP4: TP5000-TESTPOINT-YEL
TP6, TP7: TP5000-TESTPOINT-ORG

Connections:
+5V: TP2.P$1; also elsewhere on the board
+24V: TP6.P$1; also elsewhere on the board
GND: TP1.P$1, TP5.P$1; also elsewhere on the board
SCL: TP4.P$1; also elsewhere on the board
SDA: TP3.P$1; also elsewhere on the board
VSENSE: TP7.P$1; also elsewhere on the board

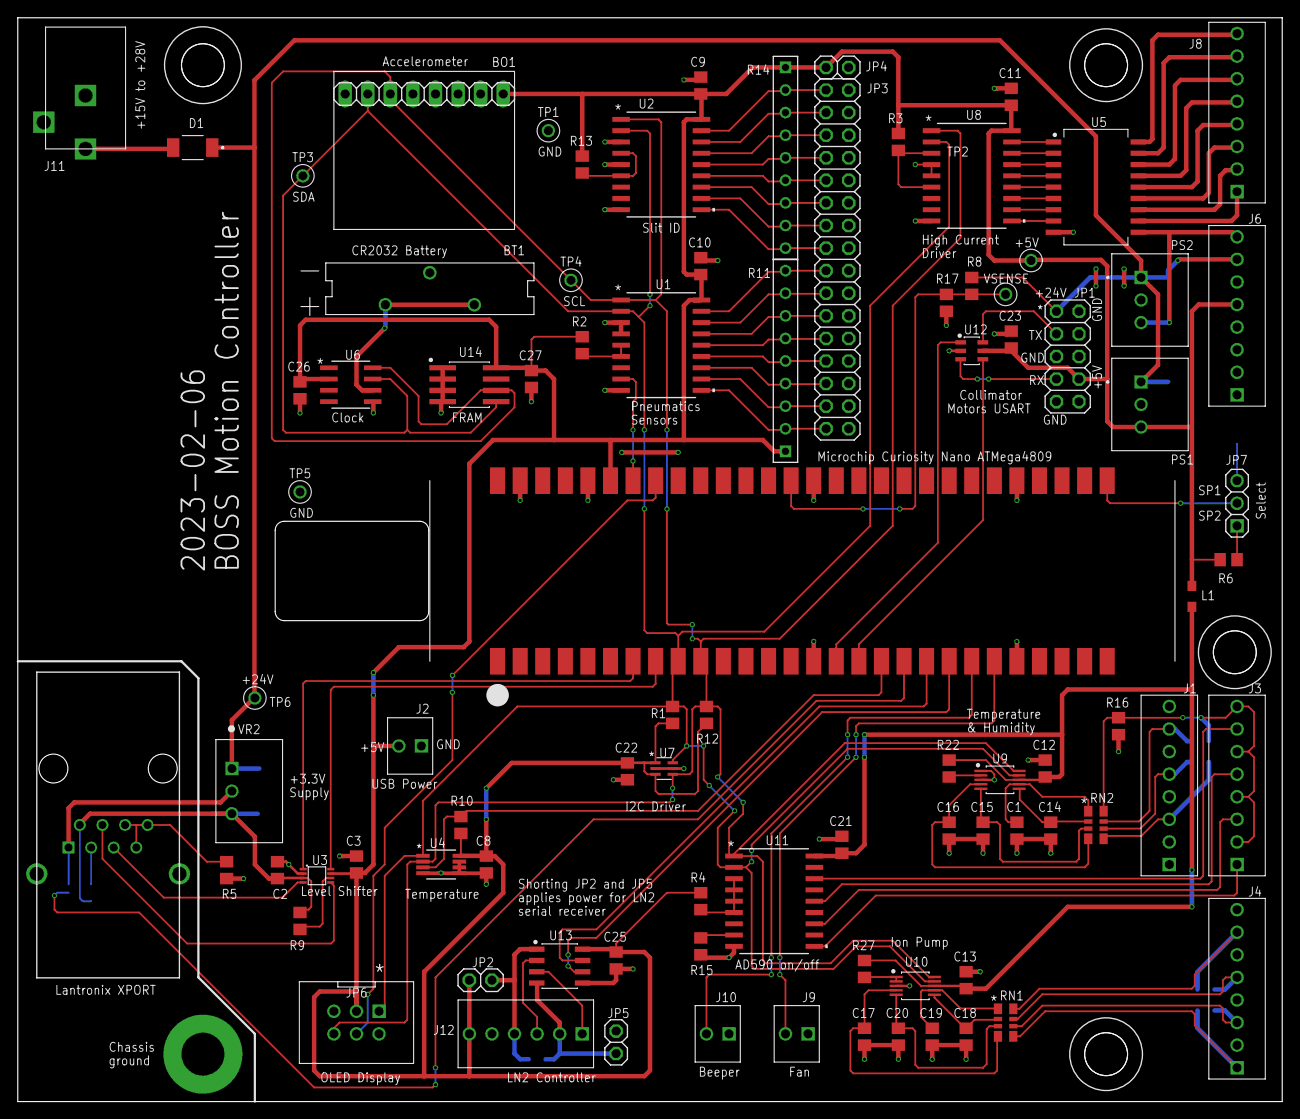
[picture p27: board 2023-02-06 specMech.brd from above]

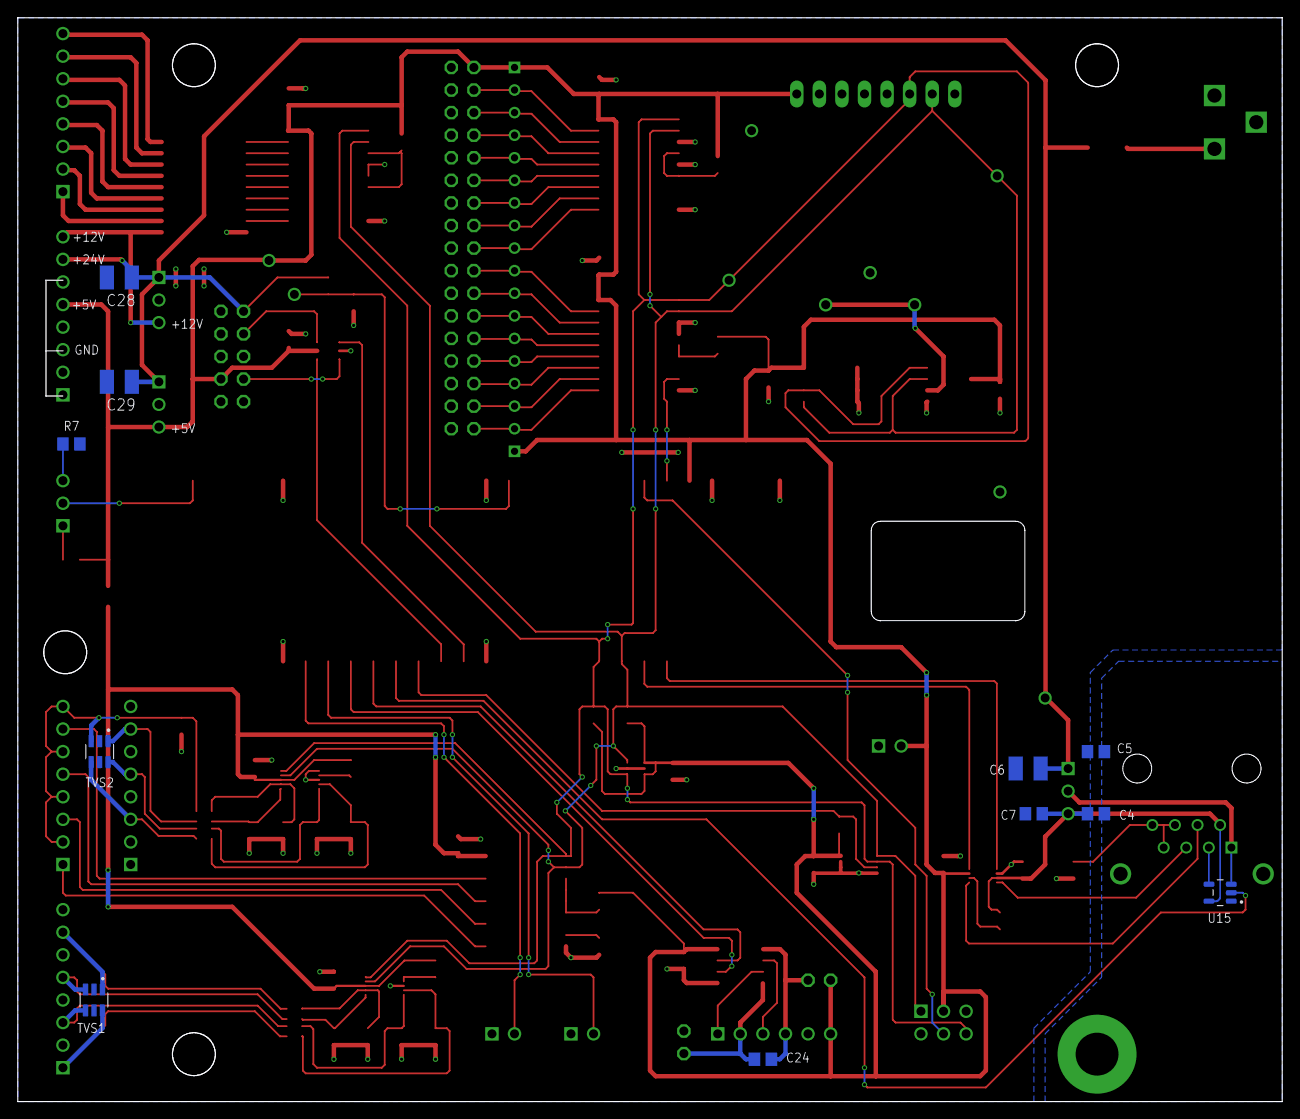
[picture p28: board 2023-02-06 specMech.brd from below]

Board: 2 copper layers, 142.2 x 121.9 mm, 100 parts (11 on the bottom side), 97 nets.

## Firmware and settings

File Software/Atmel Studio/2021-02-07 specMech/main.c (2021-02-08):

/*------------------------------------------------------------------------------
specMech.c
	BOSS motion controller board based on an ATMega4809 implemented on a
	Microchip Curiosity Nano
------------------------------------------------------------------------------*/

#define CVALUESIZE		41	// Maximum length of a command value string
#define CIDSIZE			9	// Maximum length of a command ID string
#define CSTACKSIZE		10	// Number of stacked up commands allowed

#include "globals.h"		// Global variables

#include <avr/io.h>
#include <util/delay.h>

//#include "ports.c"			// ATMega4809 port initializations
//#include "led.c"			// On-board LED
//#include "beeper.c"			// Beeper
//#include "specid.c"			// Spectrograph ID jumper
//#include "twi.c"			// I2C
//#include "mcp23008.c"		// MCP23008 port expander
//#include "pneu.c"			// Pneumatic valves and sensors
#include "ads1115.c"		// ADS1115 ADC
#include "ad590.c"			// AD590 temperature sensors
#include "mcp9808.c"		// MCP9808 sensor
#include "temperature.c"	// AD590 and MCP9808 sensors
#include "humidity.c"		// Honeywell HiH-4031
#include "ionpump.c"		// Read the ion pump vacuum
//#include "usart.c"			// Serial (RS232) communications
#include "fram.c"			// FRAM memory
//#include "ds3231.c"			// Day-time clock
//#include "mma8451.c"		// Accelerometer
//#include "nmea.c"			// GPS style output
//#include "oled.c"			// Newhaven OLED displays
//#include "eeprom.c"			// ATMega4809 eeprom
#include "wdt.c"			// Watchdog timer used only for reboot function

//#include "rtc.c"			// Real time clock one second ticks


// Function Prototypes
void commands(void);
void echo_cmd(char *str);
uint8_t isaletter(char);
void parse_cmd(char*, uint8_t);
uint8_t report(uint8_t);
void send_prompt(uint8_t);
uint8_t set(uint8_t);
void initialize(void);

typedef struct {
	char cverb,			// Single character command
	cobject,			// Single character object
	cvalue[CVALUESIZE],	// Input value string for object
	cid[CIDSIZE];		// Command ID string
} ParsedCMD;

ParsedCMD pcmd[CSTACKSIZE];	// Split the command line into its parts

uint8_t specMechErrors;

int main(void)
{

//	char strbuf[11];
	initialize();


/*
	writestr_OLED(1, "specMech Version", 1);
	get_VERSION(strbuf);
	writestr_OLED(1, strbuf, 2);
*/

	init_PORTS();
	init_LED();
	init_BEEPER();
	init_SPECID();
	init_TWI();
	init_PNEU();
	init_USART();
	init_OLED(0);
	init_OLED(1);
	init_EEPROM();
	init_MMA8451();

	sei();

	specMechErrors = 0;
	for (;;) {
		if (recv0_buf.done) {
			recv0_buf.done = NO;
			commands();
		}
	}

}

/*------------------------------------------------------------------------------
void commands(void)
	Command loop
------------------------------------------------------------------------------*/
void commands(void)
{

	char cmdline[BUFSIZE];			// BUFSIZE is the size of the ring buffer
	char verb, object;
	uint8_t i, prompt_flag = GREATERPROMPT;
	static uint8_t rebootnack = 1;
	static uint8_t cstack = 0;		// Index for pcmd

on_BEEPER();
_delay_ms(50);
off_BEEPER();

	// Copy the command string to cmdline
	for (i = 0; i < BUFSIZE; i++) {
		cmdline[i] = recv0_buf.data[recv0_buf.tail];
		recv0_buf.tail = (recv0_buf.tail + 1) % BUFSIZE;
		if (cmdline[i] == '\0') {
			break;
		}
	}

	// Check if rebooted
	if (rebootnack) {
		if (cmdline[0] != '!') {
			send_prompt(EXCLAIMPROMPT);		
			return;
		} else {
			send_prompt(GREATERPROMPT);
			rebootnack = 0;
			return;
		}
	}

	// Echo the command back to the user
	echo_cmd(cmdline);

//writestr_OLED(0, cmdline, 1);
writestr_OLED(1, cmdline, 1);

	if (strlen(cmdline) == 0) {		// Catch a terminal cr
		send_prompt(GREATERPROMPT);
		return;
	}

	parse_cmd(cmdline, cstack);
	verb = pcmd[cstack].cverb;
	object = pcmd[cstack].cobject;

	switch (verb) {
		case 'c':				// close
			prompt_flag = close_PNEU(object);
			break;

		case 'o':				// open
			prompt_flag = open_PNEU(object);
			break;

		case 'r':				// Report
			prompt_flag = report(cstack);
			break;

		case 's':				// Set
			prompt_flag = set(cstack);
			break;

		case 'R':				// Reboot
			send_prompt(GREATERPROMPT);
			_delay_ms(100);		// Avoid finishing the command loop before reboot
			reboot();
			return;

		default:
			prompt_flag = ERRORPROMPT;
			break;			
	}

	cstack = (cstack + 1) % CSTACKSIZE;
	send_prompt(prompt_flag);

}

/*------------------------------------------------------------------------------
void echo_cmd(char *cmdline)
	Echo the command line back to the user, adding the NMEA header and checksum.
------------------------------------------------------------------------------*/
void echo_cmd(char *cmdline)
{

	char format_CMD[] = "$S%dCMD,%s";
	char strbuf[BUFSIZE+10];		// Add $SXCMD, and *HH checksum

		// Format and echo the command line
	sprintf(strbuf, format_CMD, get_SPECID(), cmdline);
	checksum_NMEA(strbuf);
	send_USART(0, (uint8_t*) strbuf, strlen(strbuf));

}
/*
void initialize(void)
{

		// Curiosity nano on-board button
	PORTF.PIN6CTRL = PORT_PULLUPEN_bm | PORT_ISC_FALLING_gc;
	init_PORTS();
	init_LED();
	init_BEEPER();
	init_RTC(64);	// Fast flashing LED before reboot ACK
	init_SPECID();
	init_TWI();
	init_PNEU();
	init_USART();
	init_OLED(0);
	init_OLED(1);
	init_EEPROM();
	init_MMA8451();

}
*/
/*------------------------------------------------------------------------------
uint8_t isaletter(char c)
	Checks if the character is in the range A-Z and a-z
------------------------------------------------------------------------------*/
uint8_t isaletter(char c)
{

	if (c >= 'a' && c <= 'z') {
		return(1);
	}

	if (c >= 'A' && c <= 'Z') {
		return(1);
	}

	return(0);

}

/*------------------------------------------------------------------------------
void parse_cmd(char *ptr, uint8_t n)
	Breaks up the command line into its components. The components are:
		verb - The command verb, a single character.
		object - The commanded object, a single character.
		value - The object's new value, a character string.
		ID - An identifier selected by the user, a character string.
	These components are in the ParsedCMD structure defined in main.c. The pcmd
	variable is a ParsedCMD array.
------------------------------------------------------------------------------*/
void parse_cmd(char *ptr, uint8_t n)
{

	uint8_t i;

		// Clear the command parts
	pcmd[n].cverb = '?';
	pcmd[n].cobject = '?';
	pcmd[n].cvalue[0] = '\0';
	pcmd[n].cid[0] = '\0';

		// Find the verb
	while (!isaletter(*ptr)) {
		if (*ptr == '\0') {
			return;
		}
		ptr++;
	}
	pcmd[n].cverb = *ptr++;

		// Find the object
	while (!isaletter(*ptr)) {
		if (*ptr == '\0') {
			return;
		}
		ptr++;
	}
	pcmd[n].cobject = *ptr++;

		// Get the value, if there is one
	for (i = 0; i < CVALUESIZE; i++) {
		if (*ptr == '\0') {
			pcmd[n].cvalue[i] = '\0';
			return;
		}
		if (*ptr == ';') {
			pcmd[n].cvalue[i] = '\0';
			break;
		}
		pcmd[n].cvalue[i] = *ptr++;
	}

		// get the command ID if there is one
	ptr++;
	for (i = 0; i < CIDSIZE; i++) {
		if (*ptr == '\0') {
			pcmd[n].cid[i] = '\0';
			return;
		}
		pcmd[n].cid[i] = *ptr++;
	}	

	return;

}

/*------------------------------------------------------------------------------
uint8_t report(char *ptr)
	Report status, including reading sensors

	Input
		*ptr - Command line pointer. Incremented to find object to report

	Output
		Prints NMEA formatted output to the serial port.

	Returns
		0 - GREATERPROMPT on success
		1 - ERRORPROMPT on error (invalid command noun)
------------------------------------------------------------------------------*/
uint8_t report(uint8_t cstack)
{

	char outbuf[BUFSIZE+10], version[11];
	char currenttime[20], lastsettime[20], boottime[20];
	const char format_BTM[] = "$S%dBTM,%s,%s";
	const char format_ENV[] = "$S%dENV,%s,%3.1fC,%1.0f%%,%3.1fC,%1.0f%%,%3.1fC,%1.0f%%,%3.1fC,%s";
	const char format_ORI[] = "$S%dORI,%s,%3.1f,%3.1f,%3.1f,%s";
	const char format_PNU[] = "$S%dPNU,%s,%c,shutter,%c,left,%c,right,%c,air,%s";
	const char format_TIM[] = "$S%dTIM,%s,%s,set,%s,boot,%s";
	const char format_VAC[] = "$S%dVAC,%s,%5.2f,redvac,%5.2f,bluevac,%s";
	const char format_VER[] = "$S%dVER,%s,%s,%s";
	float t0, t1, t2, t3, h0, h1, h2;		// temperature and humidity
	float x, y, z;							// accelerometer
	float redvac, bluvac;					// red and blue vacuum
	char shutter, left, right, air;

	switch(pcmd[cstack].cobject) {

		case 'B':					// Boot time
			get_BOOTTIME(boottime);
			sprintf(outbuf, format_BTM, get_SPECID(), boottime, pcmd[cstack].cid);
			checksum_NMEA(outbuf);
			send_USART(0, (uint8_t*) outbuf, strlen(outbuf));
			break;

		case 'e':					// Environment (temperature & humidity)
			t0 = get_temperature(0);
			h0 = get_humidity(0);
			t1 = get_temperature(1);
			h1 = get_humidity(1);
			t2 = get_temperature(2);
			h2 = get_humidity(2);
			t3 = get_temperature(3);
			get_time(currenttime);
			sprintf(outbuf, format_ENV, get_SPECID(), currenttime, t0, h0, t1, h1, t2, h2, t3, pcmd[cstack].cid);
			checksum_NMEA(outbuf);
			send_USART(0, (uint8_t*) outbuf, strlen(outbuf));
			break;

		case 'o':					// Orientation
			get_orientation(MMA8451ADDR, &x, &y, &z);
			get_time(currenttime);
			sprintf(outbuf, format_ORI, get_SPECID(), currenttime, x, y, z, pcmd[cstack].cid);
//			sprintf(outbuf, "x=%03.1f y=%03.1f z=%03.1f", x, y, z);
			checksum_NMEA(outbuf);
			send_USART(0, (uint8_t*) outbuf, strlen(outbuf));
			break;

		case 'p':
			get_time(currenttime);
			read_pneusensors(&shutter, &left, &right, &air);
			sprintf(outbuf, format_PNU, get_SPECID(), currenttime, shutter, left, right, air, pcmd[cstack].cid);
			checksum_NMEA(outbuf);
			send_USART(0, (uint8_t*) outbuf, strlen(outbuf));
			break;

		case 't':					// Report current time on specMech clock
			get_time(currenttime);
			read_FRAM(FRAMADDR, SETTIMEADDR, (uint8_t*) lastsettime, 20);
			get_BOOTTIME(boottime);
			sprintf(outbuf, format_TIM, get_SPECID(), currenttime, lastsettime,
				boottime, pcmd[cstack].cid);
			checksum_NMEA(outbuf);
			send_USART(0, (uint8_t*) outbuf, strlen(outbuf));
			break;

		case 'v':
			redvac = read_ionpump(REDPUMP);
			bluvac = read_ionpump(BLUEPUMP);
			get_time(currenttime);
			sprintf(outbuf, format_VAC, get_SPECID(), currenttime, redvac, bluvac, pcmd[cstack].cid);
			checksum_NMEA(outbuf);
			send_USART(0, (uint8_t*) outbuf, strlen(outbuf));
			break;

		case 'V':
			get_VERSION(version);	// Send the specMech version
			get_time(currenttime);
			sprintf(outbuf, format_VER, get_SPECID(), currenttime, version, pcmd[cstack].cid);
			checksum_NMEA(outbuf);
			send_USART(0, (uint8_t*) outbuf, strlen(outbuf));
			break;

		default:
			return(ERRORPROMPT);
			break;
	}

	return(GREATERPROMPT);

}

/*------------------------------------------------------------------------------
void send_prompt(uint8_t prompt_flag)
	Puts a command line prompt on the output line. These could be the normal
	greater than (>) for a successful transaction, or an NMEA error line
	followed by the greater than (>).

	If specMech is rebooted, it will only prompt with a single exclamation
	point (!) until it receives an acknowledgment in the form of a single !.
------------------------------------------------------------------------------*/
void send_prompt(uint8_t prompt_flag)
{

	const char str0[] = ">";
	const char str1[] = "!";

	char prompt_str[25];

	switch (prompt_flag) {
		case GREATERPROMPT:
			strcpy(prompt_str, str0);
			send_USART(0, (uint8_t*) prompt_str, strlen(prompt_str));
			break;

		case ERRORPROMPT:
			format_ERR(prompt_str);
			send_USART(0, (uint8_t*) prompt_str, strlen(prompt_str));
			strcpy(prompt_str, str0);
			send_USART(0, (uint8_t*) prompt_str, strlen(prompt_str));
			break;

		case EXCLAIMPROMPT:
			strcpy(prompt_str, str1);
			send_USART(0, (uint8_t*) prompt_str, strlen(prompt_str));
			break;

		default:
			strcpy(prompt_str, str1);
			send_USART(0, (uint8_t*) prompt_str, strlen(prompt_str));
			break;

	}

}

/*------------------------------------------------------------------------------
uint8_t set (char *ptr)

	Input:
		cstack - The array index in the ParsedCMD array (pcmd). The command
			must have been parsed already

	Returns:
		GREATERPROMPT on success
		ERRORPROMPT if an invalid object was requested.
------------------------------------------------------------------------------*/
uint8_t set(uint8_t cstack)
{

	char object;

	object = pcmd[cstack].cobject;

	switch(object) {
		case 't':
			if (strlen(pcmd[cstack].cvalue) != 19) {
				return(ERRORPROMPT);
			}
			put_time(pcmd[cstack].cvalue);
			write_FRAM(FRAMADDR, SETTIMEADDR, (uint8_t*) pcmd[cstack].cvalue, 20);
			break;

		default:
			return(ERRORPROMPT);
	}
	return(GREATERPROMPT);
}

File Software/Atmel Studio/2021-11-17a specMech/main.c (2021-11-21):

/*------------------------------------------------------------------------------
specMech.c
	BOSS motion controller based on a Microchip Curiosity Nano with an
	ATMega4809 microcontroller.
------------------------------------------------------------------------------*/

#include "globals.h"
#include "errors.h"
#include "initialize.h"
#include "usart.h"
#include "roboclaw.h"
#include "oled.h"
#include "commands.h"

#include "fram.h"	// remove after testing

ParsedCMD pcmd[CSTACKSIZE];	// Split the command line into its parts

uint8_t firstpass;

int main(void)
{

	firstpass = YES;		// Set to NO in commands.c
	squelchErrors = YES;
	initialize();
	squelchErrors = NO;

	for (;;) {
		if (recv0_buf.done) {
			recv0_buf.done = NO;
			commands();
		}
		if (timerOLED > timeoutOLED) {	// Display timeout
			squelchErrors = YES;
			clear_OLED(0);
			clear_OLED(1);
			timerOLED = 0;
			squelchErrors = NO;
		} if ((timerSAVEENCODER > timeoutSAVEENCODER) && rebootackd) {
			squelchErrors = YES;

char str[80];
uint8_t tbuf[4];
int32_t encoderValue;

get_MOTOREncoder(128, ROBOREADENCODERCOUNT, &encoderValue);
tbuf[0] = (encoderValue >> 24) & 0xFF;
tbuf[1] = (encoderValue >> 16) & 0xFF;
tbuf[2] = (encoderValue >> 8) & 0xFF;
tbuf[3] = encoderValue & 0xFF;
write_FRAM(FRAMTWIADDR, ENCAFRAMADDR, tbuf, 4);
sprintf(str, "saved encval = %ld", encoderValue);
printLine(str);

/*
read_FRAM(FRAMTWIADDR, ENCAFRAMADDR, tbuf, 4);
encoderValue =  (uint32_t) tbuf[0] << 24;
encoderValue |= (uint32_t) tbuf[1] << 16;
encoderValue |= (uint32_t) tbuf[2] << 8;
encoderValue |= (uint32_t) tbuf[3];
sprintf(str, "saved and re-read encval = %ld", encoderValue);
printLine(str);
*/


/*
encoderValue = 250000;
set_MOTOREncoder(128, encoderValue);
encoderValue = 0;
get_MOTOREncoder(128, ROBOREADENCODERCOUNT, &encoderValue);
sprintf(str, "encval = %ld", encoderValue);
printLine(str);
*/

//			saveFRAM_MOTOREncoders();
			timerSAVEENCODER = 0;
			squelchErrors = NO;
		}
	}
}

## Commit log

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2020-10-19 Added Eagle schematic and board files
    These are far from final.
    [specMech.brd, specMech.sch]
2020-10-21 Worked on board layout
    [specMech.brd, specMech.sch]
2020-10-26 Remove backup Eagle files
    [specMech.brd, specMech.sch]
2020-10-28 Fixed level shifter orientation
    [specMech.brd]
2020-10-29 Change name to include BOSS
    [specMech.brd, specMech.sch]
2020-10-30 Added Schmitt trigger to RoboClaw interface
    [specMech.brd, specMech.sch]
2020-10-30 Added RTC & battery
    [specMech.brd, specMech.sch]
2020-10-30 Rearranged parts on board
    [specMech.brd, specMech.sch]
2020-11-01 Removed XPORT hole over pad, general cleanup
    [specMech.brd, specMech.sch]
2020-11-01 ADC area layout improvements
    [specMech.brd]
2020-11-01 Add shorting jumper to ADC ground
    [specMech.brd, specMech.sch]
2020-11-01 Removed errant character at end of brd file
    [specMech (2).brd, specMech (3).brd, specMech - Copy (2).brd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]
2020-11-01 Rearrange ADC chips after brd file recovery
    [specMech (2).brd, specMech (3).brd, specMech - Copy (2).brd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]
2020-11-01 Rearranging parts
    [specMech.brd, specMech.sch]
2020-11-01 Added ADC ground plane
    [specMech.brd]
2020-11-01 Routed high current lines
    [specMech.brd, specMech.sch]
2020-11-04 Fixed accelerometer footprint
    [specMech.brd, specMech.sch]
2020-11-04 Connected pneumatic sensor interrupt
    [specMech.brd, specMech.sch]
2020-11-04 Added Ground Overpasses
    [specMech.brd, specMech.sch]
2020-11-04 Moved wire for USB port clearance on Nano board
    [specMech.brd, specMech.sch]
2020-11-06 Partitioned grounds (removed analog ground)
    [specMech.brd, specMech.sch]
2020-11-06 Updated board label
    [specMech.brd]
2020-11-06 Enlarged USB connector clearance hole
    [specMech.brd]
2020-11-06 Problem pushing to fusion
    [specMech - Copy.brd, specMech - Copy.sch, specMech.brd]
2020-11-06 Reverting to change label time
    [specMech.brd]
2020-11-06 Used later version of XPORT-2
    [specMech.brd, specMech.sch]
2020-11-07 Finish for the day
    [specMech.sch]
2020-11-07 Connected VOFF to GND
    [specMech.brd, specMech.sch]
2020-11-09 Added +5V power for USB isolator (JST 2-pin header)
    [specMech.brd, specMech.sch]
2020-11-09 Changed FRAM footprint to allow both IC sizes
    [specMech.brd, specMech.sch]
2020-11-10 Added spectrograph selection jumper
    [specMech.brd, specMech.sch]
2020-11-10 Fixed label errors in humidity sensor input lines
    [specMech.brd, specMech.sch]
2020-11-10 Added test points, changed conflicting i2c address
    [specMech.brd, specMech.sch]
2020-11-11 Added some part values, changed date on label
    [specMech.brd, specMech.sch]
2020-11-11 Added cutout for USB connector, cleaned up some traces
    [specMech.brd]
2020-11-12 Submitted this one (Rev0) for fab to Oshpark
    2020-11-12 specMech Rev0
    [specMech.brd, specMech.sch]
2020-11-18 Added future change notes to schematic
    [specMech.sch]
2020-11-19 Removed old backup files
    [specMech - Copy.brd, specMech - Copy.sch]
2020-11-26 Added OLED-Display
    [OLED-Display.brd, OLED-Display.sch]
2020-11-27 Added pullup note to schematic
    [OLED-Display.sch]
2020-12-12 Printed 2020-11-12 Schematic
    [specMech.sch]
2020-12-15 Made copy of 2020-11-12 version
    [2020-11-12 specMech.brd, 2020-11-12 specMech.sch, OLED-Display - Copy.sch]
2020-12-26 Recover Github error?
    [specMech.brd, specMech.sch]
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2021-01-19 OLED Display minor mods
    [OLED-Display.brd, OLED-Display.sch]
2021-01-25 Removed error mesg on empty <CR>
    [main.c]
2021-01-26 Starting major changes
    Moved ferrite bead
    [specMech.brd]
2021-01-26 Swapped castellated board in, starting rerouting
    [specMech.brd, specMech.sch]
2021-01-26 More routing
    [specMech.brd, specMech.sch]
2021-01-27 More routing, mostly OK now
    [specMech.brd]
2021-01-27 Molex 1x2 header replaces JST header
    [specMech.brd, specMech.sch]
2021-01-27 Added TVS diodes on ADC inputs
    [specMech.brd, specMech.sch]
2021-01-27 Moved the accelerometer a bit away from board edge
    [specMech.brd]
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2021-02-06 Enabled button to reboot
    [main.c, oled.c, ports.c]
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2021-02-08 Updated part number for high current driver
    [specMech.brd, specMech.sch]
2021-02-08 USB Cutout in board bigger; software debugging
    [specMech.brd]
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2021-02-10 Changed LN2 connector pinout to swap rx & tx
    [specMech.brd, specMech.sch]
2021-02-13 Added fan control
    [2020-11-12 specMech.brd, TerminalBlock.sch, specMech.brd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]
2021-02-14 Changed to 7-bit TWI addresses everywhere
    [TerminalBlock.sch, specMech.sch]
2021-02-17 Forced rebootack to be !<CR> EXACTLY
    [2020-11-12 specMech.brd, 2020-11-12 specMech.sch]
2021-02-18 Added XPort reset & changed OLED display connector
    [BOSS-USB-Isolator.sch, specMech.brd, specMech.sch]
2021-02-20 Added 10uF cap on 5V dc-dc input
    [specMech.brd, specMech.sch]
2021-02-22 Labeled Fan connector
    [specMech.brd]
2021-02-22 separated uart tracks a bit
    [specMech.brd]
2021-02-24 trying to fix the hacking problem; clamped input buffer overflow
    [globals.h, main.c, usart.c]
2021-02-24 Recompiled with XPort reset on reboot
    [globals.h, main.c]
2021-02-27 Renamed USART lines to match Curiosity designations
    [specMech.brd, specMech.sch]
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2021-03-10 More RoboClaw improvements (catching errors)
    [main.c]
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2021-04-20 Minor board edits
    [2021-03-30 specMech.brd, 2021-03-30 specMech.sch, 2021-04-15 specMech.brd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]
2021-04-21 Saved 2021-04-21 version
    [2021-04-21 specMech.brd, 2021-04-21 specMech.sch]
2021-04-22 Added 24V sense line
    [specMech.brd, specMech.sch]
2021-04-22 Connected MCP9808 temp sensor alert line
    [specMech.brd, specMech.sch]
2021-05-20 Made 2021-04-22 copy for build
    [2021-04-22 specMech.brd, 2021-04-22 specMech.sch]
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2021-11-23 Fixed motor runaway and pneumatics reads
    [globals.h, main.c, ports.c]
2021-11-25 9600 baud (doesn't work at 38400 anymore?)
    [2021-11-24.cfg]
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2021-11-26 Replaced get_MOTORFloat with get_MOTOR_FLOAT
    [main.c]
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2021-11-30 Added motor ID to error reports
    [2021-11-30.cfg]
2021-12-02 Started homing routine development
    [2021-12-01.cfg]
2021-12-13 Removed circular buffer on USART1, added stop command
    [2021-12-12.cfg]
2021-12-17 Motor working again; interim state
    [2021-12-14.cfg, 2021-12-15.cfg]
2021-12-18 Minor cleanup; motors still work
    [2021-12-17.cfg]
2021-12-22 Improved serial connection to motor; seems reliable now
    [2021-12-18.cfg, 2021-12-21a.cfg]
2022-04-24 Added get_MOTOR_LIMIT (not tested)
    [2021-05-21 specMech.sch, specMech.sch]
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2022-05-01 Added new motor PD parameter files
    [2021-11-24.cfg, 2021-11-30.cfg, 2021-12-12.cfg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]
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2022-05-24 Cleaned up hardware backup copies
    [specMech.sch]
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2023-02-06 Added power to LN2 serial connection
    [2023-02-06 specMech.brd, 2023-02-06 specMech.sch]

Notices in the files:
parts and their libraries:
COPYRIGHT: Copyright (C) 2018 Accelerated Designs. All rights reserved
